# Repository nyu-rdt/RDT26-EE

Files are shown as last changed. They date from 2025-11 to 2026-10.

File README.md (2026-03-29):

# RDT26-EE
NYU Robotic Design Team Electrical Engineering subsystem repo

For help with C/C++ or using git and github, refer to training presentations in the NYU RDT 2025 - 2026 / Electrical Engineering / EE Trainings google drive

## CI Status



- `platformio-main.yml` compiles `platformio_projects/RDT_2025_26_TEENSY4_1`
- `platformio-i2c-parent.yml` compiles `general_testing/ALL_i2c_can/i2c_parent_CAN`

Both workflows run on push/pull request when those folders change, and can also be run manually from the Actions tab.

## where is the robot code?

Embedded code for robot control is / will be in [/platformio_projects](./platformio_projects). code from last years robot is in [/platformio_archive](./platformio_archive) (useful to review!) check readmes to identify the right project to use.

Review docs in [/docs](./docs) for coding style, testing, and contributing guidelines.

## where are the PCBs?

all PCBs, schematics etc. are in the Google Drive or in [/HARDWARE](./HARDWARE) folder

## new files
pls try and keep new files organized in the right folders - e.g. tests in /tests, docs in /docs, hardware files in /HARDWARE etc.

when testing things try and use the platformio test framework instead of making throwaway files.

If you do need to make such files (really want to use arduino IDE or something) please place them in [/general_testing](./general_testing) so they don't clutter the main repo.

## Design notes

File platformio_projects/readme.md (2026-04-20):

# project usage:

flags in config are mostly for testing. could move thos to test folder somehow probably. change their boolean values to enable/disable features like ramping and command timeout.

### if youre only testing:
0. connect through usb to the i2c **parent**, power child on by connecting the 3S battery
1. ensure i2c wiring is correct (sda to sda, scl to scl, gnd to gnd)
2. if code is already uploaded to both mcus just open serial monitor with `pio device monitor`
3. if you need to upload code, use the commands below. you can open two serial monitors at once to see both sides of the i2c communication and join them in vscode to see them together, or do it one at a time (in that case upload the main code first)

#### to upload main code:

```bash
pio run -t upload -d platformio_projects/RDT_2025_26_TEENSY4_1
```
or
```bash
pio run -t upload -d platformio_projects/RDT_2025_26_TEENSY4_1 --upload-port COM3
```
(upload port is optional if you just have one mcu plugged in)

#### upload test file:

```bash
pio run -t upload -d platformio_projects/i2c_parent --upload-port COM4
```
(replace COM3/4 with your actual ports - you can see which ones are connected in port menu under you terminal in vscode)

sometimes this will act up, then disconnect the other usb from your laptop while uploading, then reconnect after upload is done and it should work fine.

## corresponding test file:

testing project for parent side i2c is [/platformio_projects/i2c_parent](./../platformio_projects/i2c_parent) - lets you send loco commands via serial (WASD in serial monitor)

## opening serial monitor(s):
```bash
pio device monitor -p COM3
```
and in another terminal:
```bash
pio device monitor -p COM4
```

you can join two terminals to see both sides at once by selecting two with ctrl and rightclicking then selecting "join terminals"

in parent terminal, control direction with WASD, speed with E and Q, and stop with X or space.

## xbox controller bridge (alternative to WASD):

instead of using the serial monitor, you can plug an xbox controller into your laptop and use `platformio_projects/controller_bridge/controller_serial.py` to send commands directly.

requires:
```
pip install pygame pyserial
```

usage:
```bash
python platformio_projects/controller_bridge/controller_serial.py COM4
```
(replace COM4 with the i2c_parent Teensy's port)

| control | action |
|---|---|
| left stick | drive forward / backward |
| right stick X | turn left / right |
| A / B / Y | excavation positions |
| LB / RB / Menu | belt outward / inward / stop |
| D-pad ←/→ | bin open / close |
| D-pad ↓/↑ | vibrate on / off |
| either trigger | E-STOP |
| View button | request sensor data (printed in terminal) |

if buttons feel wrong, run with `--debug` to identify your controller's axis/button indices:
```bash
python platformio_projects/controller_bridge/controller_serial.py --debug
```

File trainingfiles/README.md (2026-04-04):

# FreeRTOS Training Projects — Teensy 4.1

Three standalone PlatformIO projects in increasing complexity. Work through them in order.

| Project | Concepts |
|---|---|
| `01_blink_rtos` | Tasks, `vTaskDelay`, `vTaskStartScheduler`, concurrency basics |
| `02_queue_mutex` | Queues, mutexes, producer/consumer pattern |
| `03_rover_i2c_can` | ISR-safe I2C→queue pipeline, task notifications, CAN bus |

---

## Setup from scratch

### 1. Create the project (PlatformIO UI)

New Project → Board: **Teensy 4.1** → Framework: **Arduino**

You get:
```
my_project/
├── include/
├── lib/
├── src/
│   └── main.cpp
└── platformio.ini
```

### 2. Edit `platformio.ini`

FreeRTOS is **not** bundled with the Teensy framework — you must declare it. Use the GitHub URL; the registry entry is unreliable.

```ini
[env:teensy41]
platform = teensy
board = teensy41
framework = arduino
monitor_speed = 115200

lib_deps =
    https://github.com/tsandmann/freertos-teensy.git
```

Add other `lib_deps` only for libraries not already bundled with Teensy. You do **not** need to add FlexCAN_T4, Wire, Servo, SPI — those ship with the Teensy framework package and are always available.

### 3. FreeRTOSConfig.h — do you need to copy it?

**No.** The library ships its own `FreeRTOSConfig.h` in its `src/` directory and `FreeRTOS.h` finds it there automatically. You do not need to copy anything for a basic build.

**Only customize it if you need to change settings.** Because `FreeRTOS.h` and `FreeRTOSConfig.h` live in the same directory inside the library, GCC always finds the library's copy first — placing one in `src/`, `include/`, or the project root does **not** override it by itself (tested).

**To override from the project root**, use the `-include` build flag in `platformio.ini`:

```ini
build_flags =
    -include "${PROJECT_DIR}/FreeRTOSConfig.h"
```

This force-injects your file before anything else, setting the `FREERTOS_CONFIG_H` include guard so the library's copy is skipped. Two caveats:
- Your config must start from the **library's** `FreeRTOSConfig.h` as a base — the port has many required settings that a generic template won't have
- If your config uses `configGENERATE_RUN_TIME_STATS == 1`, add `#include <stdint.h>` before the `uint64_t` declaration (it's injected before system headers are available)
- After changing the config, run `pio run -t clean` first — stale cached objects will cause linker errors

### 4. Customizing FreeRTOSConfig.h (optional)

You don't need to touch most of it. The fields that matter:

```c
configTICK_RATE_HZ       1000       // 1ms tick — standard, leave it
configMAX_PRIORITIES     10         // priority levels 0–9; reduce if you don't need many
configMINIMAL_STACK_SIZE 128        // words (not bytes) for the idle task stack
configUSE_MUTEXES        1          // required by port's C++ threading layer
configUSE_TASK_NOTIFICATIONS 1      // set 1 if you use xTaskNotify
configTOTAL_HEAP_SIZE    0          // 0 = use system malloc (Teensy port default)
```

Everything else either has a safe default or gets stripped by the linker if unused.

Two things already set correctly in the template:
- `configCPU_CLOCK_HZ = F_CPU` — uses the Arduino macro, matches your actual Teensy clock speed automatically
- `configSYSTICK_CLOCK_HZ = 100000UL` — Teensy-specific SysTick setting, don't change it

### 5. Write main.cpp

Include order matters for Teensy + FreeRTOS:

```cpp
#include <Arduino.h>      // always first
#include "FreeRTOS.h"
#include "task.h"
// other RTOS headers (queue.h, semphr.h, ...)
// then your own headers
```

Structure:

```cpp
void MyTask(void *pvParams) {
    for (;;) {
        // task body
        vTaskDelay(pdMS_TO_TICKS(100));
    }
}

void setup() {
    // init hardware here, before the scheduler starts
    xTaskCreate(MyTask, "MyTask", 512, NULL, 1, NULL);
    vTaskStartScheduler(); // never returns
}

void loop() {} // leave empty — the RTOS replaces loop()
```

### 6. Build

`pio run` — first build after adding lib_deps downloads the library (~30s). Subsequent builds are fast.

---

## What needs lib_deps vs what doesn't

| Library | Needs lib_deps? | Notes |
|---|---|---|
| `FlexCAN_T4` | No | Bundled with Teensy framework |
| `Wire`, `SPI`, `Servo` | No | Bundled |
| `freertos-teensy` | **Yes** | Use GitHub URL |
| `HX711` (bogde) | Yes | |
| `Encoder` (paulstoffregen) | Yes | |

---

## Key RTOS concepts by project

### 01 — Tasks and scheduling

`xTaskCreate(fn, name, stackWords, param, priority, handle)` registers a function as a task. Once `vTaskStartScheduler()` is called, the scheduler runs the highest-priority ready task. `loop()` is never called again.

`vTaskDelay(pdMS_TO_TICKS(N))` suspends the calling task for N milliseconds and lets other tasks run. Unlike Arduino `delay()`, other tasks keep executing while this one sleeps.

### 02 — Queues and mutexes

`xQueueCreate(depth, itemSize)` allocates a queue. `xQueueSend` copies data in; `xQueueReceive` blocks until data arrives. The queue owns the data — no shared pointers, no races.

A mutex (`xSemaphoreCreateMutex`) protects a shared resource. Pattern: `xSemaphoreTake → use resource → xSemaphoreGive`. Always release it, even on error paths. Never hold a mutex across a `vTaskDelay`.

**Interactive experiments** — all knobs are in `02_queue_mutex/include/config.h`. Change one value, flash, and watch Serial.

| Experiment | What to change | What to observe |
|---|---|---|
| A — fill the queue | `CONSUMER_SLOW_MS` → `2000` | `queue waiting` climbs to `QUEUE_DEPTH`, then "[Producer] WARNING: queue full" appears |
| B — drain it back | Restore `CONSUMER_SLOW_MS` → `0` | `queue waiting` drops to 0 within a few seconds |
| C — shrink the buffer | `QUEUE_DEPTH` → `1`, `PRODUCER_PERIOD_MS` → `100` | Drops appear almost every cycle |
| D — watch heap drop | `TASK_STACK_WORDS` → `4096` | `free heap` in status block drops by ~43 KB (3 tasks × 3584 extra words × 4 bytes) |
| E — stack overflow | `TASK_STACK_WORDS` → `96` | Overflow hook fires immediately; device halts — reset to recover |

The status block prints every `PRINTER_PERIOD_MS` ms. Reduce it to `500` if you want faster feedback during experiments.

### 03 — ISR safety and task notifications

Wire callbacks run at interrupt level. Two rules:
1. Never call blocking RTOS functions from an ISR
2. Use `*FromISR` variants only: `xQueueSendFromISR`, `xSemaphoreGiveFromISR`, etc.
3. Always call `portYIELD_FROM_ISR(woken)` at the end of the ISR

Task notifications are lighter than queues for single-flag signals. `xTaskNotify(handle, value, eSetValueWithOverwrite)` sends directly to a task handle. The receiving task calls `xTaskNotifyWait`. Used in project 03 to bypass the command queue for E-stop — guarantees the stop takes effect at the top of the next motor cycle regardless of what's queued.

`vTaskDelayUntil(&lastWake, period)` is the correct way to write a fixed-period task. `vTaskDelay(20)` drifts by execution time each cycle; `vTaskDelayUntil` wakes at absolute tick intervals.

**Interactive experiments** — all knobs are in `03_rover_i2c_can/include/config.h`. Requires a second Teensy sending I2C commands (or use `general_testing/ALL_i2c_can/i2c_parent_CAN`).

| Experiment | What to change | What to observe |
|---|---|---|
| A — CAN without hardware | `SIMULATE_CAN` → `0` (no motors connected) | System freezes; E-stop does nothing — CAN bus-off error-interrupt storm starves all tasks |
| B — I2C queue overflow | `I2C_QUEUE_DEPTH` → `2`, send a burst of commands | ISR drops bytes; commands arrive garbled or not at all |
| C — motor queue overflow | `MOTOR_QUEUE_DEPTH` → `1`, send commands faster than 20ms | "[I2CDecode] WARNING: motor queue full" appears |
| D — instant speed | `MAX_SPEED_DELTA_PER_TICK` → `0.5` | `[CAN SIM]` speed jumps to target in one tick instead of ramping |
| E — slow ramp | `MAX_SPEED_DELTA_PER_TICK` → `0.002` | Speed takes ~10s to reach full; useful for seeing the slew effect |
| F — command timeout | `COMMAND_TIMEOUT_MS` → `100`, stop sending I2C | `[CAN SIM]` speeds ramp to 0 within 100ms of the last command |
| G — E-stop debounce | `ESTOP_DEBOUNCE_MS` → `1` | Brief noise on pin 3 triggers false E-stops |
| H — stack vs heap | `MOTOR_TASK_STACK` → `4096` | Free heap drops by ~14 KB; visible if you add a `Serial.printf` in the motor loop |

> **Note on experiment A:** the freeze happens because the CAN controller has no termination resistor and no ACK from any node. It accumulates TX errors, enters bus-off, and the error-recovery interrupt fires thousands of times per second — faster than FreeRTOS can schedule tasks. `SIMULATE_CAN 1` skips the real write and prints `[CAN SIM]` lines instead.

---

## Reference

- FreeRTOS docs: https://www.freertos.org/Documentation/00-Overview
- tsandmann port: https://github.com/tsandmann/freertos-teensy

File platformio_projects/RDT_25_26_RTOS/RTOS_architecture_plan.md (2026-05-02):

# RTOS Detailed Architecture Plan

## 1) Purpose

This document turns the exploration notes into a concrete implementation plan for the RTOS migration.

Primary goals:
- Use hardware timing for stepper pulse generation
- Use normalized command/state plumbing for deterministic behavior
- Keep safety decisions centralized and enforceable
- Preserve software telemetry and software e-stop command handling during hardware kill-switch e-stop

## 2) Architecture Decisions Locked In

1. Stepper pulse timing is moved to hardware timer ISR (not loop cadence).
2. I2C receive ISR stays minimal and only pushes bytes to queue.
3. Commands are decoded into normalized desired-state data (not direct module calls in ISR path).
4. Safety owns timeout detection and publishes safety bits globally.
5. Actuator tasks enforce safety bits every cycle.
6. While hardware kill-switch is active:
   - Allow `GRP_CONTROL` and `GRP_DATA`
   - Reject motion/mechanism command groups

## 3) High-Level Topology

```mermaid
flowchart LR
    J[Jetson / I2C Master] --> RXISR[I2C RX ISR]
    RXISR --> QRX[(qI2cRxBytes)]
    QRX --> CMD[CmdDecodeTask]
    CMD --> DS[(DesiredState)]

    SAF[SafetyTask] --> EGS[(EventGroup: SafetyBits)]
    SAF -->|notify hard-stop| MOT[MotorControlTask]
    SAF -->|notify hard-stop| MEC[MechanismTask]

    DS --> MOT
    DS --> MEC
    EGS --> MOT
    EGS --> MEC

    MOT --> MCAN{{mCanTx}}
    MEC --> MCAN
    MCAN --> CAN[CAN Driver]

    MEC --> STEPPLAN[(StepperPulsePlan)]
    STEPISR[Stepper Timer ISR] --> STEPDRV[STEP pin pulses]
    STEPPLAN --> STEPISR

    SNS[SensorTask] --> SNAP[(SensorSnapshot)]
    EGS --> TEL[TelemetryTask]
    SNAP --> TEL
    TEL --> TBUF[(Telemetry Buffer A/B)]
    REQISR[I2C Request ISR] --> TBUF
    TBUF --> J
```

## 4) Task Set and Scheduling

Assumption: `configMAX_PRIORITIES = 10` (0 is idle).

| Task | Priority | Trigger | Period/Block | Initial Stack (words) | Responsibility |
|---|---:|---|---|---:|---|
| `SafetyTask` | 7 | periodic | 5 ms | 512 | Relay status, timeout detection, safety bit updates, hard-stop notifications |
| `DebugTask` | 1 | periodic | 50-100 ms | 640 | Serial/Teleplot output only |

Interrupt handlers:
- I2C RX ISR: queue push only (`xQueueSendFromISR`)
- I2C Request ISR: send latest ready telemetry buffer only
- Stepper Timer ISR: pin toggling only, no RTOS API calls

## 5) RTOS Primitives

### Queues

| Name | Type | Depth | Producer | Consumer | Notes |
|---|---|---:|---|---|---|
| `qI2cRxBytes` | `uint8_t` | 32 | I2C RX ISR | `CmdDecodeTask` | Byte ingress decoupling; overflow counter for diagnostics |

### Event Group

`egSafetyBits` (written by `SafetyTask`, read by control tasks):
- `SAFETY_HW_ESTOP`
- `SAFETY_SW_ESTOP`
- `SAFETY_COMMS_TIMEOUT`
- `SAFETY_OVERCURRENT`
- `SAFETY_LATCHED_STOP` (optional if we want explicit reset semantics)

### Mutexes

| Name | Protects | Users |
|---|---|---|
| `mCanTx` | CAN peripheral transaction sequence | `MotorControlTask`, `MechanismTask` |
| `mDesiredState` | `DesiredState` struct | `CmdDecodeTask` writer, actuator task readers |

### Task Notifications

- `SafetyTask` -> `MotorControlTask`: hard-stop notification bit
- `SafetyTask` -> `MechanismTask`: hard-stop notification bit

Use notifications for low-latency stop signaling; use event bits for persistent safety state.

## 6) Shared Data Contracts

### `DesiredState`

Single source of operator intent, updated only by `CmdDecodeTask`.

```c
typedef struct {
    float loco_left_target;      // normalized -1..1 after duty scaling
    float loco_right_target;     // normalized -1..1 after duty scaling
    float excav_belt_target;     // normalized -1..1 after duty scaling
    int8_t excav_vert_dir;       // -1,0,+1
    int8_t depo_door_cmd;        // -1 close, 0 hold, +1 open
    int8_t depo_vib_cmd;         // -1,0,+1
    uint32_t last_cmd_ms;        // for timeout logic
} DesiredState;
```

### `SensorSnapshot`

Prepared by `SensorTask`, read by `TelemetryTask` and optional debug.

### `StepperPulsePlan`

Shared with timer ISR.

```c
    volatile uint8_t enabled;        // 0/1
    volatile uint8_t dir;            // 0=down, 1=up
```

## 7) Hardware-Timed Stepper Plan

Implementation strategy:
1. Configure `IntervalTimer` at boot with an ISR callback.
2. ISR toggles STEP pin each invocation if `enabled==1`.
3. `MechanismTask` updates `StepperPulsePlan` (dir/enabled/period) from desired state and limits.
4. ISR reads plan and runs without dynamic allocation, queues, or prints.

Benefits:
- Pulse quality independent of RTOS task jitter
- Cleaner mechanism task code (task makes decisions, ISR makes pulses)
- Easier to prove maximum missed-step risk

Constraints:
- Use `digitalWriteFast` or direct GPIO for ISR speed
- Keep ISR constant-time and branch-light
- Guard shared plan updates with critical section or atomic write strategy

## 8) Command Policy and Gating

Command validation is centralized in `CmdDecodeTask`. The kill-switch gating policy has been validated against the prototype and is kept as-is:

```text
if HW kill-switch estop active:
  allow groups: CONTROL, DATA
  reject groups: locomotion, excavation, deposition
else:
  allow all valid groups
```

SW can still send software e-stop/reset semantics. Actuator-changing commands are blocked while hardware e-stop is active.

For any multi-byte command extension, axis/register mapping must be defined explicitly in named constants before field deployment. Parser tests covering both axis variants are required before any multi-byte extension ships. This was a source of ambiguity in the prototype and is a hard guardrail going forward.

## 9) Control Flow Sequences

```mermaid
sequenceDiagram
    participant Master as I2C Master
    participant DS as DesiredState

    CMD->>DS: write normalized targets (mutex)
```

```mermaid
sequenceDiagram
    participant SAF as SafetyTask

    SAF->>SAF: read relay + now-last_cmd_ms
    SAF-->>MEC: notify hard-stop if asserted
    MOT->>MOT: force outputs zero if any safety-stop bit
```

```mermaid
sequenceDiagram
    participant BUF as Double Buffer
    participant REQ as I2C Request ISR

    SNS->>TEL: latest sensor snapshot
    REQ->>BUF: read active packet pointer
    REQ->>Master: Wire2.write(packet, DATA_PACKET_SIZE)
```

## 10) Safety State Ownership

Single-writer policy:
- `SafetyTask` is the only writer of `egSafetyBits`.

Consumers:
- `CmdDecodeTask` reads for command gating.
- `MotorControlTask` and `MechanismTask` read for enforcement.
- `TelemetryTask` reads for packet flags.

This avoids conflicting stop logic spread across multiple modules.

The low-latency task notification path from `SafetyTask` to actuator tasks is kept in addition to the persistent event bits — the notification handles the immediate hard-stop response, the bits handle steady-state enforcement. Both are required.

## 11) File/Module Layout (Planned)

```text
RDT_25_26_RTOS/
  include/
    rtos_types.h
    rtos_config.h
    safety_bits.h
  src/
    main.cpp
    rtos/
      app_init.cpp
      isr_i2c.cpp
      isr_stepper_timer.cpp
      task_safety.cpp
      task_cmd_decode.cpp
      task_motor_control.cpp
      task_mechanism.cpp
      task_sensor.cpp
      task_telemetry.cpp
      task_debug.cpp
      shared_state.cpp
```

## 12) Step-by-Step Implementation Plan

### Phase A: Kernel scaffold
- Add FreeRTOS lib dependency
- Create task skeletons and all RTOS primitives
- Keep outputs disabled by default

### Phase B: Safety backbone
- Implement `SafetyTask` + safety event bits
- Add hard-stop notification path to control tasks
- Add counters for transitions and timeout events

### Phase C: Command plumbing
- Add RX ISR queue and `CmdDecodeTask`
- Implement normalized `DesiredState`
- Implement command gating rules for kill-switch mode
- Define all multi-byte command axis/register mappings as named constants at this phase; do not defer

### Phase D: Actuator control tasks
- Move locomotion/excav belt CAN logic into `MotorControlTask` (20 ms)
- Move deposition + stepper control decisions into `MechanismTask` (5 ms)
- Introduce hardware timer ISR for stepper pulse generation

### Phase E: Sensors and telemetry
- Add `SensorTask` snapshot generation
- Add `TelemetryTask` packet build + double buffer
- Keep I2C request ISR minimal and deterministic
- Keep legacy telemetry packet compatibility for parent bring-up tools
- Add explicit byte-count assertions for every serialized `GRP_DATA` register; these must be verified against the active superloop serializer, not assumed

### Phase F: Debug and tuning
- Add debug task
- Enable stack high-water mark and heap monitoring behind a debug flag during migration; remove or gate behind flag before competition build
- Tune queue depths, task stacks, and periods using measured runtime

## 13) Acceptance Criteria

1. With kill-switch e-stop active:
   - Data request responses continue at expected packet length
   - `GRP_CONTROL` accepted
   - Motion/mechanism command groups rejected

2. Timeout behavior:
   - No command for `COMMAND_TIMEOUT_MS` sets timeout safety bit
   - Actuator outputs are forced to safe state within one control period

3. Stepper timing:
   - Pulse jitter stays bounded by timer ISR, independent of command burst load

4. Stability:
   - No queue overflows in normal command rate
   - If overflow occurs, system remains safe and counters expose fault

5. Parent compatibility:
   - `i2c_parent` command keys (`WASD`, excavation, deposition, stop, estop) operate the RTOS child without protocol remapping
   - Legacy data request path returns expected packet length for current bench scripts; this must be verified with an explicit test that sends a `GRP_DATA` request and checks the response byte count

6. Pin parity:
   - Child pin assignments for relay, current mux, encoders, stepper, deposition door, and vib motor match the active superloop `pins.h` unless explicitly documented as variant-only
   - Migration acceptance includes a cross-check against the active superloop pin map; undocumented divergences are a blocking failure

7. Protocol robustness:
   - Multi-byte command extensions include explicit axis/register mapping constants
   - Serializer outputs are verified against expected byte lengths per register; encode/decode round-trip checks are required for all bit-packed telemetry fields

## 14) Instrumentation to Add Early

- `i2c_rx_overflow_count`
- `cmd_rejected_killswitch_count`
- `cmd_decode_invalid_count`
- `timeout_event_count`
- `safety_transition_count`
- `max_task_exec_us` per critical task
- `telemetry_serialize_error_count`
- `i2c_response_short_packet_count`

These make bring-up and competition debugging much faster.

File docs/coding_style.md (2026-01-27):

# Coding Style Guide

Guidelines for keeping the codebase readable. Not strict rules - use your judgment.

This doc is also useful context for AI assistants (Copilot, Claude, etc.) when working on the codebase.

---

## Naming

| Thing | Style | Example |
|---|---|---|
| Files | `snake_case` | `can_driver.cpp` |
| Functions | Module prefix + descriptive | `CAN_SendSpeed()`, `Sensors_Init()` |
| Variables | `camelCase` | `motorSpeed`, `encoderCount` |
| Constants | `ALL_CAPS` | `CAN_BAUD_RATE`, `PIN_MOTOR_PWM` |

The module prefix (like `CAN_`, `Sensors_`) helps identify where functions come from since C++ doesn't have namespaces in the Arduino world.

---

## File Structure

**Header files (.h):**
```cpp
#ifndef MODULE_NAME_H
#define MODULE_NAME_H

#include <Arduino.h>

void Module_Init(void);
void Module_DoThing(int param);

#endif
```

**Source files (.cpp):**
```cpp
#include "module_name.h"
#include "config.h"

static int s_internalVariable = 0;  // static = file-private

void Module_Init(void) {
    // setup code
    Serial.println("Module ready");
}

void Module_DoThing(int param) {
    // implementation
}
```

---

## Comments

```cpp
// Use comments to explain WHY, not WHAT
// Bad: increment counter
// Good: increment to track missed CAN messages for timeout detection

// Mark things that need attention
// TODO: add timeout handling
// FIXME: this breaks if speed > 1.0
// VERIFIED: tested on hardware 2026-01-26

// For functions that others will call, brief description is helpful
/**
 * Send speed command to motor over CAN
 * @param canId Motor's CAN address
 * @param speed -1.0 to 1.0
 */
void CAN_SendSpeed(uint32_t canId, float speed);
```

---

## Hardware-Specific Stuff

**Put all pins in config.h:**
```cpp
// config.h
#define PIN_MOTOR_PWM       11
#define PIN_ESTOP_RELAY     2
#define PIN_STRING_POT      A3
```

**Volatile for interrupt variables:**
```cpp
volatile long encoderCount = 0;  // modified in ISR

void encoderISR(void) {
    encoderCount++;
}
```

**Protect shared data:**
```cpp
long getEncoderCount(void) {
    noInterrupts();
    long count = encoderCount;
    interrupts();
    return count;
}
```

---

## Avoid Magic Numbers

```cpp
// Bad
if (reading > 512) { ... }

// Good
#define SENSOR_THRESHOLD 512
if (reading > SENSOR_THRESHOLD) { ... }
```

---

## Error Handling

Check if things worked, especially hardware:
```cpp
if (!CAN_Init()) {
    Serial.println("ERROR: CAN failed to init");
    // handle it somehow
}
```

---

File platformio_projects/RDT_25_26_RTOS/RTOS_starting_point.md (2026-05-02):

# RTOS Starting Point

Reference projects:
- `trainingfiles/01_blink_rtos`
- `trainingfiles/02_queue_mutex`
- `trainingfiles/03_rover_i2c_can`

Common setup pattern:
- `platformio.ini` adds `https://github.com/tsandmann/freertos-teensy.git`
- `setup()` creates tasks and calls `vTaskStartScheduler()`
- `loop()` is intentionally empty
- `Arduino.h` is included before FreeRTOS headers
- ISR paths use `*FromISR` APIs and `portYIELD_FROM_ISR(...)`

Architecture pattern used in `03_rover_i2c_can`:
- ISR only captures bytes quickly and pushes to a queue
- Decode/command logic runs in a task
- Motor control runs in a fixed-period task (`vTaskDelayUntil`)
- E-stop runs in a high-priority task and notifies motor task directly

This pattern is a strong match for our current rover firmware constraints.

## Current superloop snapshot (RDT_2025_26_TEENSY4_1)

`ROVER_update()` currently does:
1. `EE_BOX_Update()`
2. E-stop relay check and possible `ESTOP_Trigger()`
3. Command handling (`newCommand` + `processCommand`)
4. Timeout check (`COMMAND_TIMEOUT_MS`)
5. Periodic subsystem updates:
   - `LOCO_Update()`
   - `EXCAV_Update()`
   - `CURRENT_SENSORS_Update()` (optional)
   - `LOAD_CELL_Update()` (optional)
   - `DEPO_Update()`
   - `COMMS_UpdateFlags()`
   - `DEBUG_Update()` (optional)

## Candidate task split

### Task A: E-stop / safety monitor (highest)
- Responsibility:
  - Read relay state (`EE_BOX_Update` + `EE_BOX_IsRelayEngaged`)
  - Trigger emergency stop immediately on unsafe state
  - Notify motor/control task of hard-stop state
- Why high priority:
  - Safety path; must preempt normal control work
- Target period:
  - 5-10 ms

### Task B: I2C RX + command decode
- Responsibility:
  - ISR captures incoming I2C bytes to queue
  - Task decodes command byte into actions/targets
  - Writes command target state (or pushes decoded command struct)
- Why:
  - Keeps ISR minimal and deterministic
  - Prevents command parsing from blocking time-critical loops
- Trigger model:
  - Event-driven via queue receive (block until data)

### Task C: Motor/control loop (locomotion + excavation command application)
- Responsibility:
  - Apply latest target commands
  - Handle ramp logic at fixed rate (`TX_PERIOD_MS = 20`)
  - Send CAN commands
  - Enforce comms timeout fail-safe
- Why:
  - This is the rover control heartbeat
  - Fixed periodic timing is important for predictable motion
- Target period:
  - 20 ms (`50 Hz`)

### Task D: Mechanism maintenance loop
- Responsibility:
  - `EXCAV_Update()` (stepper + limit logic + optional pot checks)
  - `DEPO_Update()` (door state machine)
- Why:
  - Mechanism internals are periodic but less safety-critical than Task A/C
- Target period:
  - 5-10 ms for stepper smoothness (or split stepper to use a hardware timer interrupt if jitter is an issue)

### Task E: Sensor + flags loop
- Responsibility:
  - `CURRENT_SENSORS_Update()`
  - `LOAD_CELL_Update()`
  - `COMMS_UpdateFlags()`
- Why:
  - These feed telemetry and health flags; useful but not motor-heartbeat critical
- Target period:
  - 10 ms for current mux stepping
  - 50-100 ms acceptable for aggregate flags publishing

### Task F: Debug/telemetry print loop (lowest)
- Responsibility:
  - `DEBUG_Update()` serial plot output
- Why low priority:
  - Human-facing output should never starve safety/control
- Target period:
  - Existing `PLOT_PERIOD_MS` (50 ms) or slower if serial load is high

## Proposed priority order (initial)

1. Task A `EStopSafety` (highest)
2. Task C `MotorControl`
3. Task B `I2CDecode`
4. Task D `MechanismUpdate`
5. Task E `SensorsAndFlags`
6. Task F `DebugTelemetry` (lowest)

Notes:
- If command latency becomes visible, raise Task B above Task C and let Task C consume latest decoded state each cycle.

## Init placement strategy

Use a two-level init pattern:

1. `setup()` does board/global bring-up before scheduler:
- Serial (optional)
- Pin mode defaults for safety outputs
- CAN peripheral init
- I2C bus init and callback registration
- Queue/mutex/task-notification primitive creation
- Task creation and scheduler start

2. Each task does module-local one-time init before its loop:
- Example: initialize task-local timestamps/state variables
- Then enter `for (;;)` loop with `vTaskDelay`/`vTaskDelayUntil`

This mirrors the training projects and keeps task ownership clear.

## Suggested migration phases

1. RTOS scaffold only:
- Add FreeRTOS dependency and empty task skeletons
- Keep behavior equivalent to current firmware

2. Move safety + command pipeline:
- Add ISR queue + decode task
- Add E-stop safety task + notification path

3. Move control heartbeat:
- Create 20 ms motor control task using `vTaskDelayUntil`
- Remove superloop control timing logic

4. Move slower periodic work:
- Sensors, flags, debug prints

5. Tune priorities and stack sizes with runtime measurements.

## Open questions before implementation

- Should stepper pulse timing stay in a shared mechanism task, or become a dedicated high-rate task or hardware timer interrupt from day one?
- Do we want timeout handling only in MotorControl (single owner), or mirrored in Safety task too?
- Should command decoding directly call handlers, or write a normalized command struct consumed by MotorControl/Mechanism tasks?

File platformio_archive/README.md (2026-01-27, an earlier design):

# PlatformIO Archive (Legacy Code)

> ⚠️ **LEGACY CODE** - This folder contains archived firmware from the 2024-2025 competition season. It is kept for reference but is no longer actively developed.

This folder contains PlatformIO-based firmware projects for the RDT26-EE excavation rover.

---

## 🎯 Project Reference

| Project | Status | Use Case |
|---|---|---|
| **[RDT_2024_PF](./RDT_2024_PF/)** | 📦 Archived | Modular architecture for Teensy 4.1 - most complete legacy code |
| [2024_teensy_original](./2024_teensy_original/) | 📦 Archived | Single-file version for Teensy 4.1 |
| [2024_STM32_migr](./2024_STM32_migr/) | ⚠️ Outdated | STM32 port - incomplete, missing features |
| [stm32_rtos_2024](./stm32_rtos_2024/) | ⚠️ Outdated | STM32 + FreeRTOS - incomplete, missing features |

**This is archived code.** For the current robot codebase, check the main repository or ask the team lead.

---

## Project Descriptions

### RDT_2024_PF (Most Complete)
**Platform:** Teensy 4.1 | **Framework:** Arduino | **Status:** 📦 Archived

The most complete archived codebase for the excavation rover. Features a clean modular architecture:
- Separate modules for locomotion, excavation, sensors, CAN, I2C, and system control
- Full support for rotary encoders, HX711 load cells, E-stop relay
- CAN bus motor control at 500kbps
- I2C slave interface for Raspberry Pi communication

```
RDT_2024_PF/
├── include/          # Header files for each module
├── src/              # Implementation files
├── lib/HX711/        # Load cell library
└── platformio.ini    # Build configuration
```

**Build:** `cd RDT_2024_PF && pio run`

See [RDT_2024_PF/README.md](./RDT_2024_PF/README.md) for detailed system documentation.

---

### 2024_teensy_original
**Platform:** Teensy 4.1 | **Framework:** Arduino

The original single-file implementation (~1000 lines in `main.cpp`). This is the reference implementation that `RDT_2024_PF` was modularized from. Contains all features but is harder to navigate and maintain.

Use this if you need to:
- Compare behavior with the modular version
- Understand the original implementation intent
- Debug issues by testing against a known-working version

**Build:** `cd 2024_teensy_original && pio run`

---

### 2024_STM32_migr
**Platform:** STM32F446RE | **Framework:** STM32Cube HAL

⚠️ **Not currently in use** - This was a port to STM32, but it's based on an older version of the code that's missing:
- Rotary encoder support
- E-stop relay handling
- CAN-based belt motor control
- Updated pin mappings

If we decide to migrate to STM32 in the future, this project will need to be updated to match `RDT_2024_PF`.

---

### stm32_rtos_2024
**Platform:** STM32F446RE | **Framework:** STM32Cube HAL + FreeRTOS

⚠️ **Not currently in use** - Same as `2024_STM32_migr` but with FreeRTOS for real-time task scheduling. Also based on outdated code.

Contains a custom FreeRTOS configuration but would need significant updates before use.

---

## Getting Started

### Prerequisites
1. Install [PlatformIO](https://platformio.org/install) (VS Code extension recommended)
2. Install Teensy platform: `pio pkg install -g -p teensy`

### Building
```bash
# Navigate to desired project
cd RDT_2024_PF

# Build
pio run

# Build and upload to connected Teensy
pio run -t upload

# Monitor serial output
pio device monitor -b 115200
```

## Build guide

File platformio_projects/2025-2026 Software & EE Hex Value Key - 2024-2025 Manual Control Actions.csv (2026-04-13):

Category | Subcategory | 1st Nibble |  | 2nd Nibble |  | Final Hex | Description
 |  | Command | Hex | Value | Hex
 |  | Emergency Stop | 0 |  | 1 | 0 1 | Still deciding whether we want commands to be remembered during a stop
Locomotion |  | Locomotion Stop | 1 | Locomotion Stop | 0 | 1 0 | Stops moving forward/ backward and turning
 |  | Forward | 2 | 25% | 0 | 2 0 | Move forward at VALUE% of max speed
 |  |  | 2 | 50% | 1 | 2 1
 |  |  | 2 | 75% | 2 | 2 2
 |  |  | 2 | 100% | 3 | 2 3
 |  | Backward | 3 | 25% | 0 | 3 0 | Move backward at VALUE% of max speed
 |  |  | 3 | 50% | 1 | 3 1
 |  |  | 3 | 75% | 2 | 3 2
 |  |  | 3 | 100% | 3 | 3 3
 |  | Left | 4 | 25% | 0 | 4 0 | Move left at VALUE% of max speed (forward in right wheels backward in left wheels)
 |  |  | 4 | 50% | 1 | 4 1
 |  |  | 4 | 75% | 2 | 4 2
 |  |  | 4 | 100% | 3 | 4 3
 |  | Right | 5 | 25% | 0 | 5 0 | Move right at VALUE% of max speed (forward in left wheels backward in right wheels)
 |  |  | 5 | 50% | 1 | 5 1
 |  |  | 5 | 75% | 2 | 5 2
 |  |  | 5 | 100% | 3 | 5 3
Excavation |  | Exacavation Conveyor Actions | 6 | Stop Excavation Conveyor | 0 | 6 0 | Store the current position of the excavation conveyor as "locomotion position"
 |  |  | 6 | Locomotion Position | 1 | 6 1 | Move the excavation conveyor to its locomotion position
 |  |  | 6 | Excavation Position | 2 | 6 2 | Move the excavation conveyor to its excavation position
 |  |  | 6 | Belt Stop | 3 | 6 3 | Stop the belt movement
 |  |  | 6 | Belt Outward | 4 | 6 4 | Move the belt in reverse
 |  |  | 6 | Belt Inward | 5 | 6 5 | Digging and collecting the material
Construction |  | Depo Bin | 7 | Open Door | 0 | 7 0 | Open depo bin door
 |  |  | 7 | Close Door | 1 | 7 1 | Close depo bin door
 |  |  | 7 | Turn on Vibration Motor | 2 | 7 2 | Turn on vibration motor to remove regolith from bin
 |  |  | 7 | Turn off Vibration Motor | 3 | 7 3 | Turn off vibration motor
Other |  | Request Data | 8 | Request data | 0 | 8 0 | sensor flags, byte data by this doc
 |  | Switch to Autonomous Control | 8 | Switch to Autonomous Control | 1 | 8 1 | Sends signal to "switch to autonomous control" and to start interpreting actions acording to the autonomous control scheme (see other sheet). Stops all motion (wheels, pivot and belt) before switching.

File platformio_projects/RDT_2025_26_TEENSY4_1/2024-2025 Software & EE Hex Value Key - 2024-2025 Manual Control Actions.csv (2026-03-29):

Category | Subcategory | 1st Nibble |  | 2nd Nibble |  | Final Hex | Description
 |  | Command | Hex | Value | Hex
 |  | Emergency Stop | 0 |  | 1 | 0 1 | Still deciding whether we want commands to be remembered during a stop
Locomotion |  | Locomotion Stop | 1 | Locomotion Stop | 0 | 1 0 | Stops moving forward/ backward and turning
 |  | Forward | 2 | 25% | 0 | 2 0 | Move forward at VALUE% of max speed
 |  |  | 2 | 50% | 1 | 2 1
 |  |  | 2 | 75% | 2 | 2 2
 |  |  | 2 | 100% | 3 | 2 3
 |  | Backward | 3 | 25% | 0 | 3 0 | Move backward at VALUE% of max speed
 |  |  | 3 | 50% | 1 | 3 1
 |  |  | 3 | 75% | 2 | 3 2
 |  |  | 3 | 100% | 3 | 3 3
 |  | Left | 4 | 25% | 0 | 4 0 | Move left at VALUE% of max speed (forward in right wheels backward in left wheels)
 |  |  | 4 | 50% | 1 | 4 1
 |  |  | 4 | 75% | 2 | 4 2
 |  |  | 4 | 100% | 3 | 4 3
 |  | Right | 5 | 25% | 0 | 5 0 | Move right at VALUE% of max speed (forward in left wheels backward in right wheels)
 |  |  | 5 | 50% | 1 | 5 1
 |  |  | 5 | 75% | 2 | 5 2
 |  |  | 5 | 100% | 3 | 5 3
Excavation/Construction |  | Exacavation Conveyor Actions | 6 | Zero Excavation Conveyor | 0 | 6 0 | Store the current position of the excavation conveyor as "locomotion position" STOP MOVEMENT OF ACME SCREW
 |  |  | 6 | Locomotion Position | 1 | 6 1 | Move the excavation conveyor to its locomotion position
 |  |  | 6 | Excavation Position | 2 | 6 2 | Move the excavation conveyor to its excavation position
 |  |  | 6 | Belt Stop | 3 | 6 3 | Stop the belt movement
 |  |  | 6 | Belt Outward | 4 | 6 4 | Move the belt in reverse
 |  |  | 6 | Belt Inward | 5 | 6 5 | Digging and collecting the material
 |  | Deposition Conveyor Actions | 7 | Rotate Collection | 0 | 7 0 | Rotating the belt to collect from the shovel into the construction bin
 |  |  | 7 | Rotate Dumping | 1 | 7 1 | Rotating the belt to move the dirt from construction
 |  |  | 7 | Stop rotating | 2 | 7 2 | Stop the belt
Other |  | Request Data | 8 | Request data | 0 | 8 0 | Weight collected, position (locomotion, excavation, deposition), distance travelled.
 |  | Switch to Autonomous Control | 8 | Switch to Autonomous Control | 1 | 8 1 | Sends signal to "switch to autonomous control" and to start interpreting actions acording to the autonomous control scheme (see other sheet). Stops all motion (wheels, pivot and belt) before switching.
 |  | 1. depo now has a door controler by a linear actuator |  | open door
 |  |  |  | close door
 |  |  |  | ???
 |  | 2. depo now has a vibration motor controlled through PWM |  | turn on
 |  |  |  | turn off
 |  |  |  | ? do we want intensity variation?

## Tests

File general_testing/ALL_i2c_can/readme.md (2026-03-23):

# all the platformio projects in this folder are for testing the i2c and can bus communication between the teensy and another teensy (to be replaced by jetson send same command strucutre)

## Currently used:

The most complete child project (that is/will be integrated into full system) is [/i2c_can_child_tony](./i2c_can_child_tony)

The project used to test it is [/i2c_parent_CAN](./i2c_parent_CAN) but obviosuly that should be handled by the software team and their python-based code on the jetson

These only have the implementation for locomotion control but they form a foundation for the rest of the system and have stubs for excav and depo. the actual project is in [/platformio_projects\RDT_2025_26_TEENSY4_1](../../platformio_projects/RDT_2025_26_TEENSY4_1)

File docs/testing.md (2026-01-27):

# Testing with PlatformIO

This guide explains how to write and run tests for the rover firmware.

---

## What Are PlatformIO Tests?

Tests let you upload **alternative code** to the Teensy to verify that specific parts of the system work correctly. Instead of running the full rover firmware, you run focused test code that exercises one subsystem at a time.

This is useful for:
- Verifying hardware works before full integration
- Debugging issues in isolation
- Testing new components as they're assembled

---

## How Testing Works

### Normal Build (`pio run`)
Compiles and uploads the main firmware from `src/main.cpp`.

### Test Build (`pio test`)
Compiles and uploads code from the `test/` folder instead. Your test file provides its own `setup()` and `loop()` functions.

The main `src/main.cpp` is **not included** during test builds—your test takes its place.

---

## Running Tests

### Run a Specific Test
```bash
pio test -f test_blink
```
This compiles and uploads just the `test_blink` test.

### Run All Tests
```bash
pio test
```
Runs each test in the `test/` folder sequentially.

### View Serial Output
Open the Serial Monitor to see test output:
```bash
pio device monitor
```

---

## Test Folder Structure

Each test lives in its own subfolder under `test/`:

```
test/
├── test_blink/
│   └── test_blink.cpp
├── test_can/
│   └── test_can.cpp
├── test_motor/
│   └── test_motor.cpp
└── test_sensors/
    └── test_sensors.cpp
```

The folder name determines the test name used with `pio test -f`.

---

## Writing a Basic Test

A test file is a complete Arduino program with `setup()` and `loop()`:

```cpp
// test/test_blink/test_blink.cpp

#include <Arduino.h>

void setup() {
    Serial.begin(115200);
    pinMode(LED_BUILTIN, OUTPUT);
    Serial.println("=== Blink Test ===");
}

void loop() {
    digitalWrite(LED_BUILTIN, HIGH);
    Serial.println("LED ON");
    delay(500);
    
    digitalWrite(LED_BUILTIN, LOW);
    Serial.println("LED OFF");
    delay(500);
}
```

Run with:
```bash
pio test -f test_blink
```

---

## Testing a Subsystem

You can import modules from `src/` and `include/` to test them:

```cpp
// test/test_can/test_can.cpp

#include <Arduino.h>
#include "can_driver.h"

void setup() {
    Serial.begin(115200);
    delay(2000);  // Wait for Serial Monitor to connect
    
    Serial.println("=== CAN Driver Test ===");
    
    // Test initialization
    if (CAN_Init()) {
        Serial.println("CAN init: PASS");
    } else {
        Serial.println("CAN init: FAIL");
        return;
    }
    
    // Test sending a message
    Serial.println("Sending test message to motor 0x78...");
    CAN_SendMotorSpeed(0x78, 0.0);
    Serial.println("Message sent - verify motor controller received it");
}

void loop() {
    // Test complete - nothing to do
}
```

---

## Interactive Testing

For hardware testing, it's often useful to control the test from the Serial Monitor:

```cpp
// test/test_motor_interactive/test_motor_interactive.cpp

#include <Arduino.h>
#include "locomotion.h"
#include "can_driver.h"

void setup() {
    Serial.begin(115200);
    delay(2000);
    
    CAN_Init();
    
    Serial.println("=== Motor Interactive Test ===");
    Serial.println("Commands:");
    Serial.println("  f = Forward");
    Serial.println("  b = Backward");
    Serial.println("  s = Stop");
}

void loop() {
    if (Serial.available()) {
        char cmd = Serial.read();
        
        switch (cmd) {
            case 'f':
                Serial.println("Moving forward...");
                Locomotion_Forward(0.25);
                break;
            case 'b':
                Serial.println("Moving backward...");
                Locomotion_Backward(0.25);
                break;
            case 's':
                Serial.println("Stopping...");
                Locomotion_Stop();
                break;
        }
    }
}
```

Open the Serial Monitor (`pio device monitor`) and type commands to control the robot.

---

## Testing Hardware Before Integration

When bringing up new hardware, write a minimal test that exercises just that component:

```cpp
// test/test_single_motor/test_single_motor.cpp
// Test one motor before wiring all four

#include <Arduino.h>
#include <FlexCAN_T4.h>

FlexCAN_T4<CAN1, RX_SIZE_256, TX_SIZE_16> can1;

#define MOTOR_CAN_ID  0x78  // Change to the motor you're testing

void setup() {
    Serial.begin(115200);
    delay(2000);
    
    can1.begin();
    can1.setBaudRate(500000);
    
    Serial.println("=== Single Motor Test ===");
    Serial.print("Testing motor ID: 0x");
    Serial.println(MOTOR_CAN_ID, HEX);
}

void loop() {
    // Send speed command
    CAN_message_t msg;
    msg.flags.extended = 1;
    msg.id = MOTOR_CAN_ID;
    msg.len = 4;
    
    int32_t speed = 25000;  // 25% speed (0.25 * 100000)
    msg.buf[0] = (speed >> 24) & 0xFF;
    msg.buf[1] = (speed >> 16) & 0xFF;
    msg.buf[2] = (speed >> 8) & 0xFF;
    msg.buf[3] = speed & 0xFF;
    
    can1.write(msg);
    Serial.println("Sent speed command");
    
    delay(100);
}
```

---

## Using the Unity Test Framework

For automated pass/fail testing, PlatformIO includes the Unity framework:

```cpp
// test/test_example/test_example.cpp

#include <Arduino.h>
#include <unity.h>
#include "can_driver.h"

void test_can_initialization(void) {
    bool result = CAN_Init();
    TEST_ASSERT_TRUE(result);
}

void test_speed_calculation(void) {
    // Test that speed conversion works correctly
    int expected = 25000;
    int actual = (int)(0.25 * 100000);
    TEST_ASSERT_EQUAL(expected, actual);
}

void setup() {
    delay(2000);
    
    UNITY_BEGIN();
    
    RUN_TEST(test_can_initialization);
    RUN_TEST(test_speed_calculation);
    
    UNITY_END();
}

void loop() {
    // Tests run in setup(), nothing needed here
}
```

Output:
```
test/test_example.cpp:7:test_can_initialization    [PASSED]
test/test_example.cpp:12:test_speed_calculation    [PASSED]
-----------------------
2 Tests 0 Failures 0 Ignored
```

### Common Unity Assertions

| Assertion | Purpose |
|---|---|
| `TEST_ASSERT_TRUE(condition)` | Verify condition is true |
| `TEST_ASSERT_FALSE(condition)` | Verify condition is false |
| `TEST_ASSERT_EQUAL(expected, actual)` | Verify integers are equal |
| `TEST_ASSERT_EQUAL_FLOAT(exp, act, delta)` | Verify floats are close |
| `TEST_ASSERT_NULL(pointer)` | Verify pointer is null |
| `TEST_ASSERT_NOT_NULL(pointer)` | Verify pointer is not null |

---

## Important Notes

### Restore Main Firmware After Testing
After running tests, the Teensy contains test code, not the main firmware. Upload the real firmware:
```bash
pio run -t upload
```

### Test One Thing at a Time
Tests are most useful when they focus on a single subsystem. If a test fails, you know exactly where the problem is.

### Keep Tests in Version Control
Test files serve as documentation for how to use each subsystem. They help new team members understand the hardware.

### Safety
When testing motors:
- Always have E-Stop accessible
- Have another person present for first-time motor tests
- Start with low speeds (25%)

---

## Quick Reference

| Command | Description |
|---|---|
| `pio test` | Run all tests |
| `pio test -f test_name` | Run specific test |
| `pio device monitor` | Open Serial Monitor |
| `pio run -t upload` | Upload main firmware |

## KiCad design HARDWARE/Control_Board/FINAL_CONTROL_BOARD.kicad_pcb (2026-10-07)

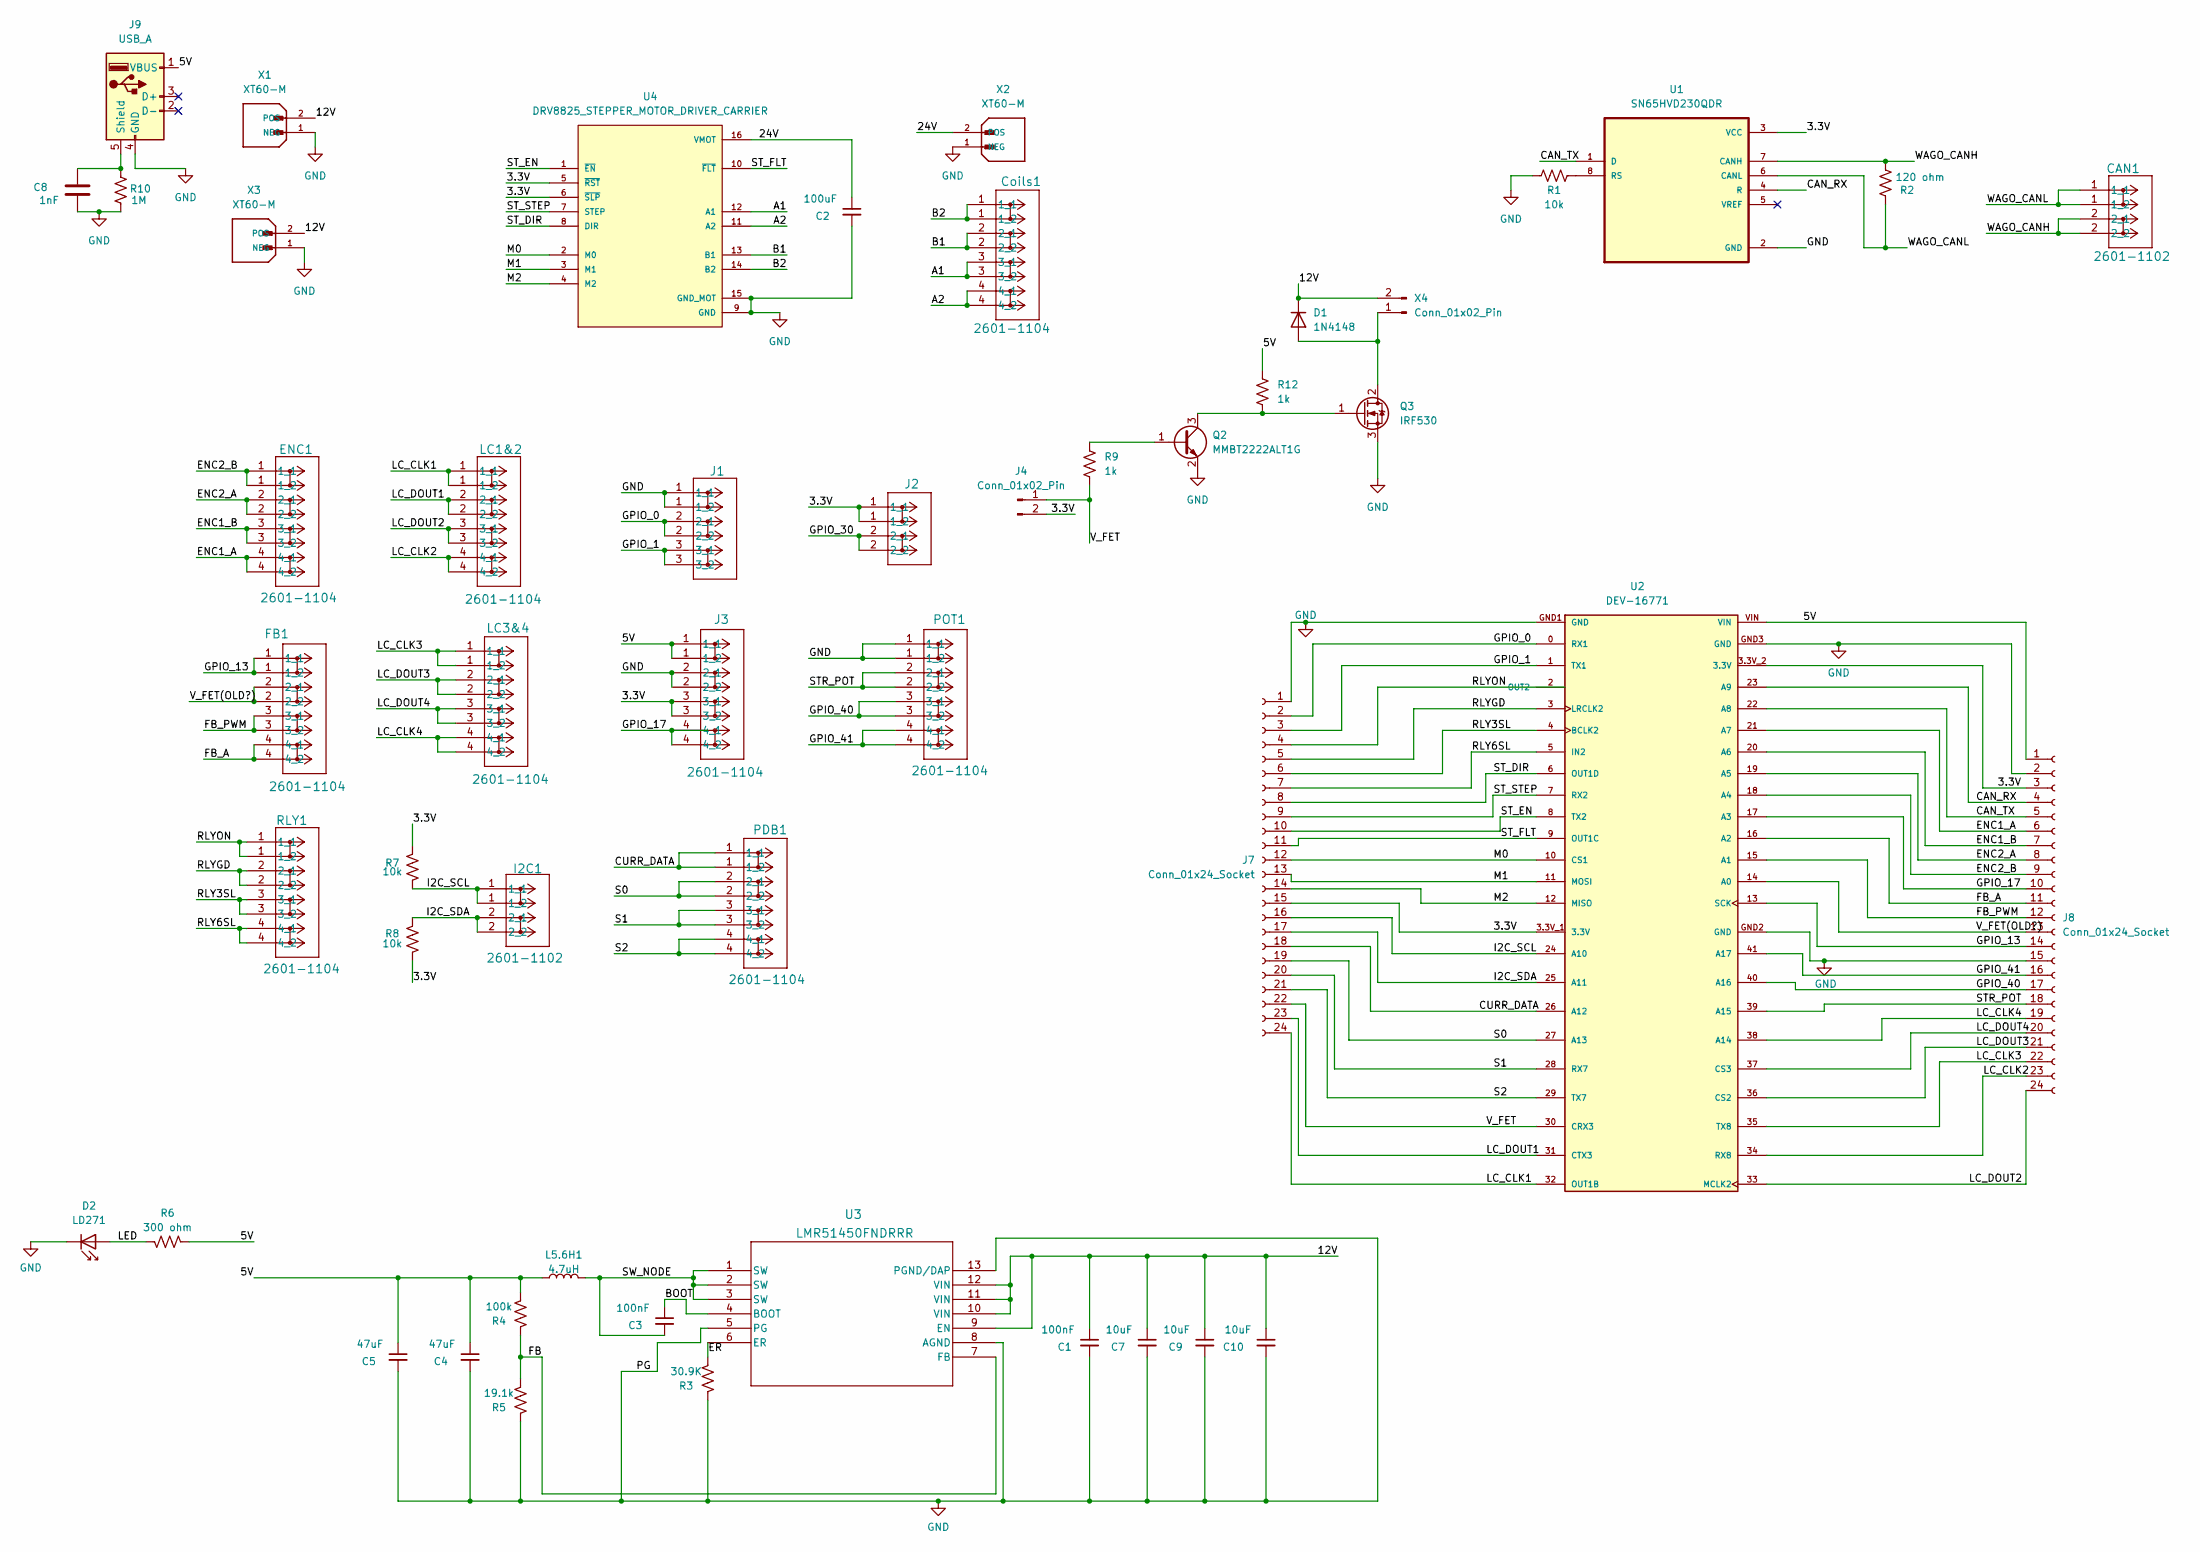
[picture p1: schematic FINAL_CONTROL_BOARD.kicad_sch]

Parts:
C1, C3: 100nF; C_0402_1005Metric_Pad0.74x0.62mm_HandSolder
C2: 100uF; C_Radial_D6.3mm_H5.0mm_P2.50mm
C4, C5: 47uF; C_1210_3225Metric_Pad1.33x2.70mm_HandSolder
C7, C9, C10: 10uF; C_0805_2012Metric_Pad1.18x1.45mm_HandSolder
C8: 1nF; C_0805_2012Metric_Pad1.18x1.45mm_HandSolder
CAN1: 2601-1102; CONN2_2601-1102_WAG
Coils1: 2601-1104; CONN4_2601-1104_WAG
D1: 1N4148; D_DO-35_SOD27_P7.62mm_Horizontal
D2: LD271; LED_D5.0mm
ENC1: 2601-1104; CONN4_2601-1104_WAG
FB1: 2601-1104; CONN4_2601-1104_WAG
I2C1: 2601-1102; CONN2_2601-1102_WAG
J1: 2604-1103; CONN3_2601-1103_WAG
J2: 236-402/334-604; CONN2_2601-1102_WAG
J3: 2601-1104; CONN4_2601-1104_WAG
J4: Conn_01x02_Pin; PinHeader_1x02_P2.54mm_Vertical
J7, J8: Conn_01x24_Socket; PinHeader_1x24_P2.54mm_Vertical
J9: USB_A; USB_A_TE_292303-4
L5.6H1: 4.7uH; L_Coilcraft_XAL6060-XXX
LC1&2, LC3&4: 2601-1104; CONN4_2601-1104_WAG
PDB1: 2601-1104; CONN4_2601-1104_WAG
POT1: 2601-1104; CONN4_2601-1104_WAG
Q2: MMBT2222ALT1G; SOT-23
Q3: IRF530; TO-220-3_Vertical
R1, R7, R8: 10k; R_0805_2012Metric
R2: 120 ohm; R_0805_2012Metric
R3: 30.9K; R_0805_2012Metric
R4: 100k; R_0805_2012Metric
R5: 19.1k; R_0805_2012Metric
R6: 300 ohm; R_0805_2012Metric
R9, R12: 1k; R_0805_2012Metric
R10: 1M; R_0805_2012Metric_Pad1.20x1.40mm_HandSolder
RLY1: 2601-1104; CONN4_2601-1104_WAG
U1: SN65HVD230QDR; SOIC127P599X175-8N
U2: DEV-16771; teensy4.1
U3: LMR51450FNDRRR; WSON_SDRRR_TEX
U4: DRV8825_STEPPER_MOTOR_DRIVER_CARRIER; IC_DRV8825_STEPPER_MOTOR_DRIVER_CARRIER
X1, X2, X3: XT60-M; AMASS_XT60-M; PARTREV V1.2
X4: Conn_01x02_Pin; AMASS_XT60-M

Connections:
/3.3V: J2.1 (1_1), J3.3 (3_1), J4.2, J7.15, J8.3, R7.2, R8.2, U1.3 (VCC), U2.3.3V_1 (3.3V), U2.3.3V_2 (3.3V), U4.5 (~RST), U4.6 (~SLP)
/5V: C4.1, C5.1, J3.1 (1_1), J8.1, J9.1 (VBUS), L5.6H1.2, R4.2, R6.2, R12.1, U2.VIN
/12V: C1.1, C7.1, C9.1, C10.1, D1.1 (K), U3.9 (EN), U3.10 (VIN), U3.11 (VIN), U3.12 (VIN), X1.2 (POS), X3.2 (POS), X4.2
/24V: C2.1, U4.16 (VMOT), X2.2 (POS)
/A1: Coils1.3 (3_1), U4.12 (A1)
/A2: Coils1.4 (4_1), U4.11 (A2)
/B1: Coils1.2 (2_1), U4.13 (B1)
/B2: Coils1.1 (1_1), U4.14 (B2)
/BOOT: C3.1, U3.4 (BOOT)
/CAN_RX: J8.4, U1.4 (R), U2.23 (A9)
/CAN_TX: J8.5, U1.1 (D), U2.22 (A8)
/CURR_DATA: J7.18, PDB1.1 (1_1), U2.26 (A12)
/ENC1_A: ENC1.4 (4_1), J8.6, U2.21 (A7)
/ENC1_B: ENC1.3 (3_1), J8.7, U2.20 (A6)
/ENC2_A: ENC1.2 (2_1), J8.8, U2.19 (A5)
/ENC2_B: ENC1.1 (1_1), J8.9, U2.18 (A4)
/ER: R3.2, U3.6 (ER)
/FB: R4.1, R5.2, U3.7 (FB)
/FB_A: FB1.4 (4_1), J8.11, U2.16 (A2)
/FB_PWM: FB1.3 (3_1), J8.12, U2.15 (A1)
/GPIO_0: J1.2 (2_1), J7.2, U2.0 (RX1)
/GPIO_1: J1.3 (3_1), J7.3, U2.1 (TX1)
/GPIO_13: FB1.1 (1_1), J8.14, U2.13 (SCK)
/GPIO_17: J3.4 (4_1), J8.10, U2.17 (A3)
/GPIO_30: J2.2 (2_1)
/GPIO_40: J8.17, POT1.3 (3_1), U2.40 (A16)
/GPIO_41: J8.16, POT1.4 (4_1), U2.41 (A17)
/I2C_SCL: I2C1.1 (1_1), J7.16, R7.1, U2.24 (A10)
/I2C_SDA: I2C1.2 (2_1), J7.17, R8.1, U2.25 (A11)
/LC_CLK1: J7.24, LC1&2.1 (1_1), U2.32 (OUT1B)
/LC_CLK2: J8.23, LC1&2.4 (4_1), U2.34 (RX8)
/LC_CLK3: J8.22, LC3&4.1 (1_1), U2.35 (TX8)
/LC_CLK4: J8.19, LC3&4.4 (4_1), U2.38 (A14)
/LC_DOUT1: J7.23, LC1&2.2 (2_1), U2.31 (CTX3)
/LC_DOUT2: J8.24, LC1&2.3 (3_1), U2.33 (MCLK2)
/LC_DOUT3: J8.21, LC3&4.2 (2_1), U2.36 (CS2)
/LC_DOUT4: J8.20, LC3&4.3 (3_1), U2.37 (CS3)
/LED: D2.2 (A), R6.1
/M0: J7.12, U2.10 (CS1), U4.2 (M0)
/M1: J7.13, U2.11 (MOSI), U4.3 (M1)
/M2: J7.14, U2.12 (MISO), U4.4 (M2)
/RLY3SL: J7.6, RLY1.3 (3_1), U2.4 (BCLK2)
/RLY6SL: J7.7, RLY1.4 (4_1), U2.5 (IN2)
/RLYGD: J7.5, RLY1.2 (2_1), U2.3 (LRCLK2)
/RLYON: J7.4, RLY1.1 (1_1), U2.2 (OUT2)
/S0: J7.19, PDB1.2 (2_1), U2.27 (A13)
/S1: J7.20, PDB1.3 (3_1), U2.28 (RX7)
/S2: J7.21, PDB1.4 (4_1), U2.29 (TX7)
/STR_POT: J8.18, POT1.2 (2_1), U2.39 (A15)
/ST_DIR: J7.8, U2.6 (OUT1D), U4.8 (DIR)
/ST_EN: J7.10, U2.8 (TX2), U4.1 (~EN)
/ST_FLT: J7.11, U2.9 (OUT1C), U4.10 (~FLT)
/ST_STEP: J7.9, U2.7 (RX2), U4.7 (STEP)
/SW_NODE: C3.2, L5.6H1.1, U3.1 (SW), U3.2 (SW), U3.3 (SW)
/V_FET: J4.1, J7.22, R9.2, U2.30 (CRX3)
/V_FET(OLD?): FB1.2 (2_1), J8.13, U2.14 (A0)
/WAGO_CANH: CAN1.2 (2_1), R2.2, U1.7 (CANH)
/WAGO_CANL: CAN1.1 (1_1), R2.1, U1.6 (CANL)
GND: C1.2, C2.2, C4.2, C5.2, C7.2, C8.2, C9.2, C10.2, D2.1 (K), J1.1 (1_1), J3.2 (2_2), J7.1, J8.2, J8.15, J9.4 (GND), POT1.1 (1_1), Q2.2 (E), Q3.3 (S), R1.1, R3.1, R5.1, R10.2, U1.2 (GND), U2.GND1 (GND), U2.GND2 (GND), U2.GND3 (GND), U3.5 (PG), U3.8 (AGND), U3.13 (PGND/DAP), U4.9 (GND), U4.15 (GND_MOT), X1.1 (NEG), X2.1 (NEG), X3.1 (NEG)
unnamed: D1.2 (A), Q3.2 (D), X4.1
unnamed: C8.1, J9.5 (Shield), R10.1
unnamed: Q2.1 (B), R9.1
unnamed: Q2.3 (C), Q3.1 (G), R12.2
unnamed: R1.2, U1.8 (RS)

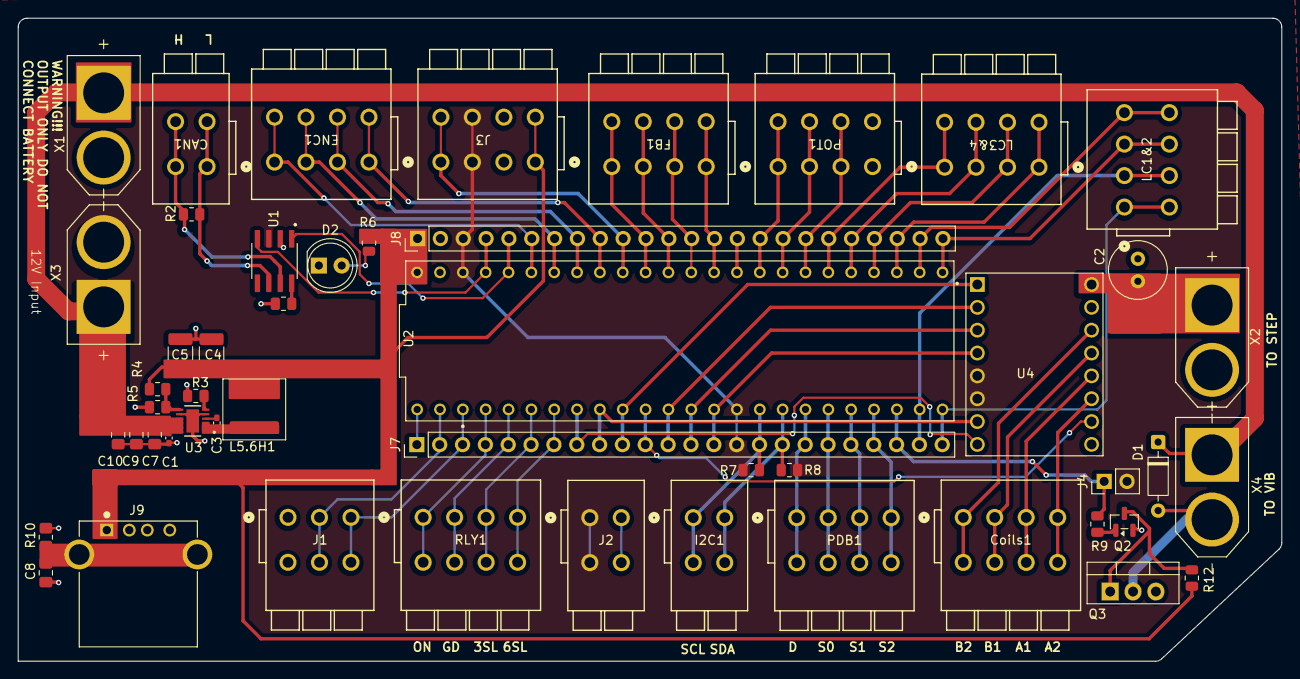
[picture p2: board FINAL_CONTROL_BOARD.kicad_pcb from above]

Board: 2 copper layers, 140.5 x 71.5 mm, 50 parts (0 on the bottom side), 63 nets.

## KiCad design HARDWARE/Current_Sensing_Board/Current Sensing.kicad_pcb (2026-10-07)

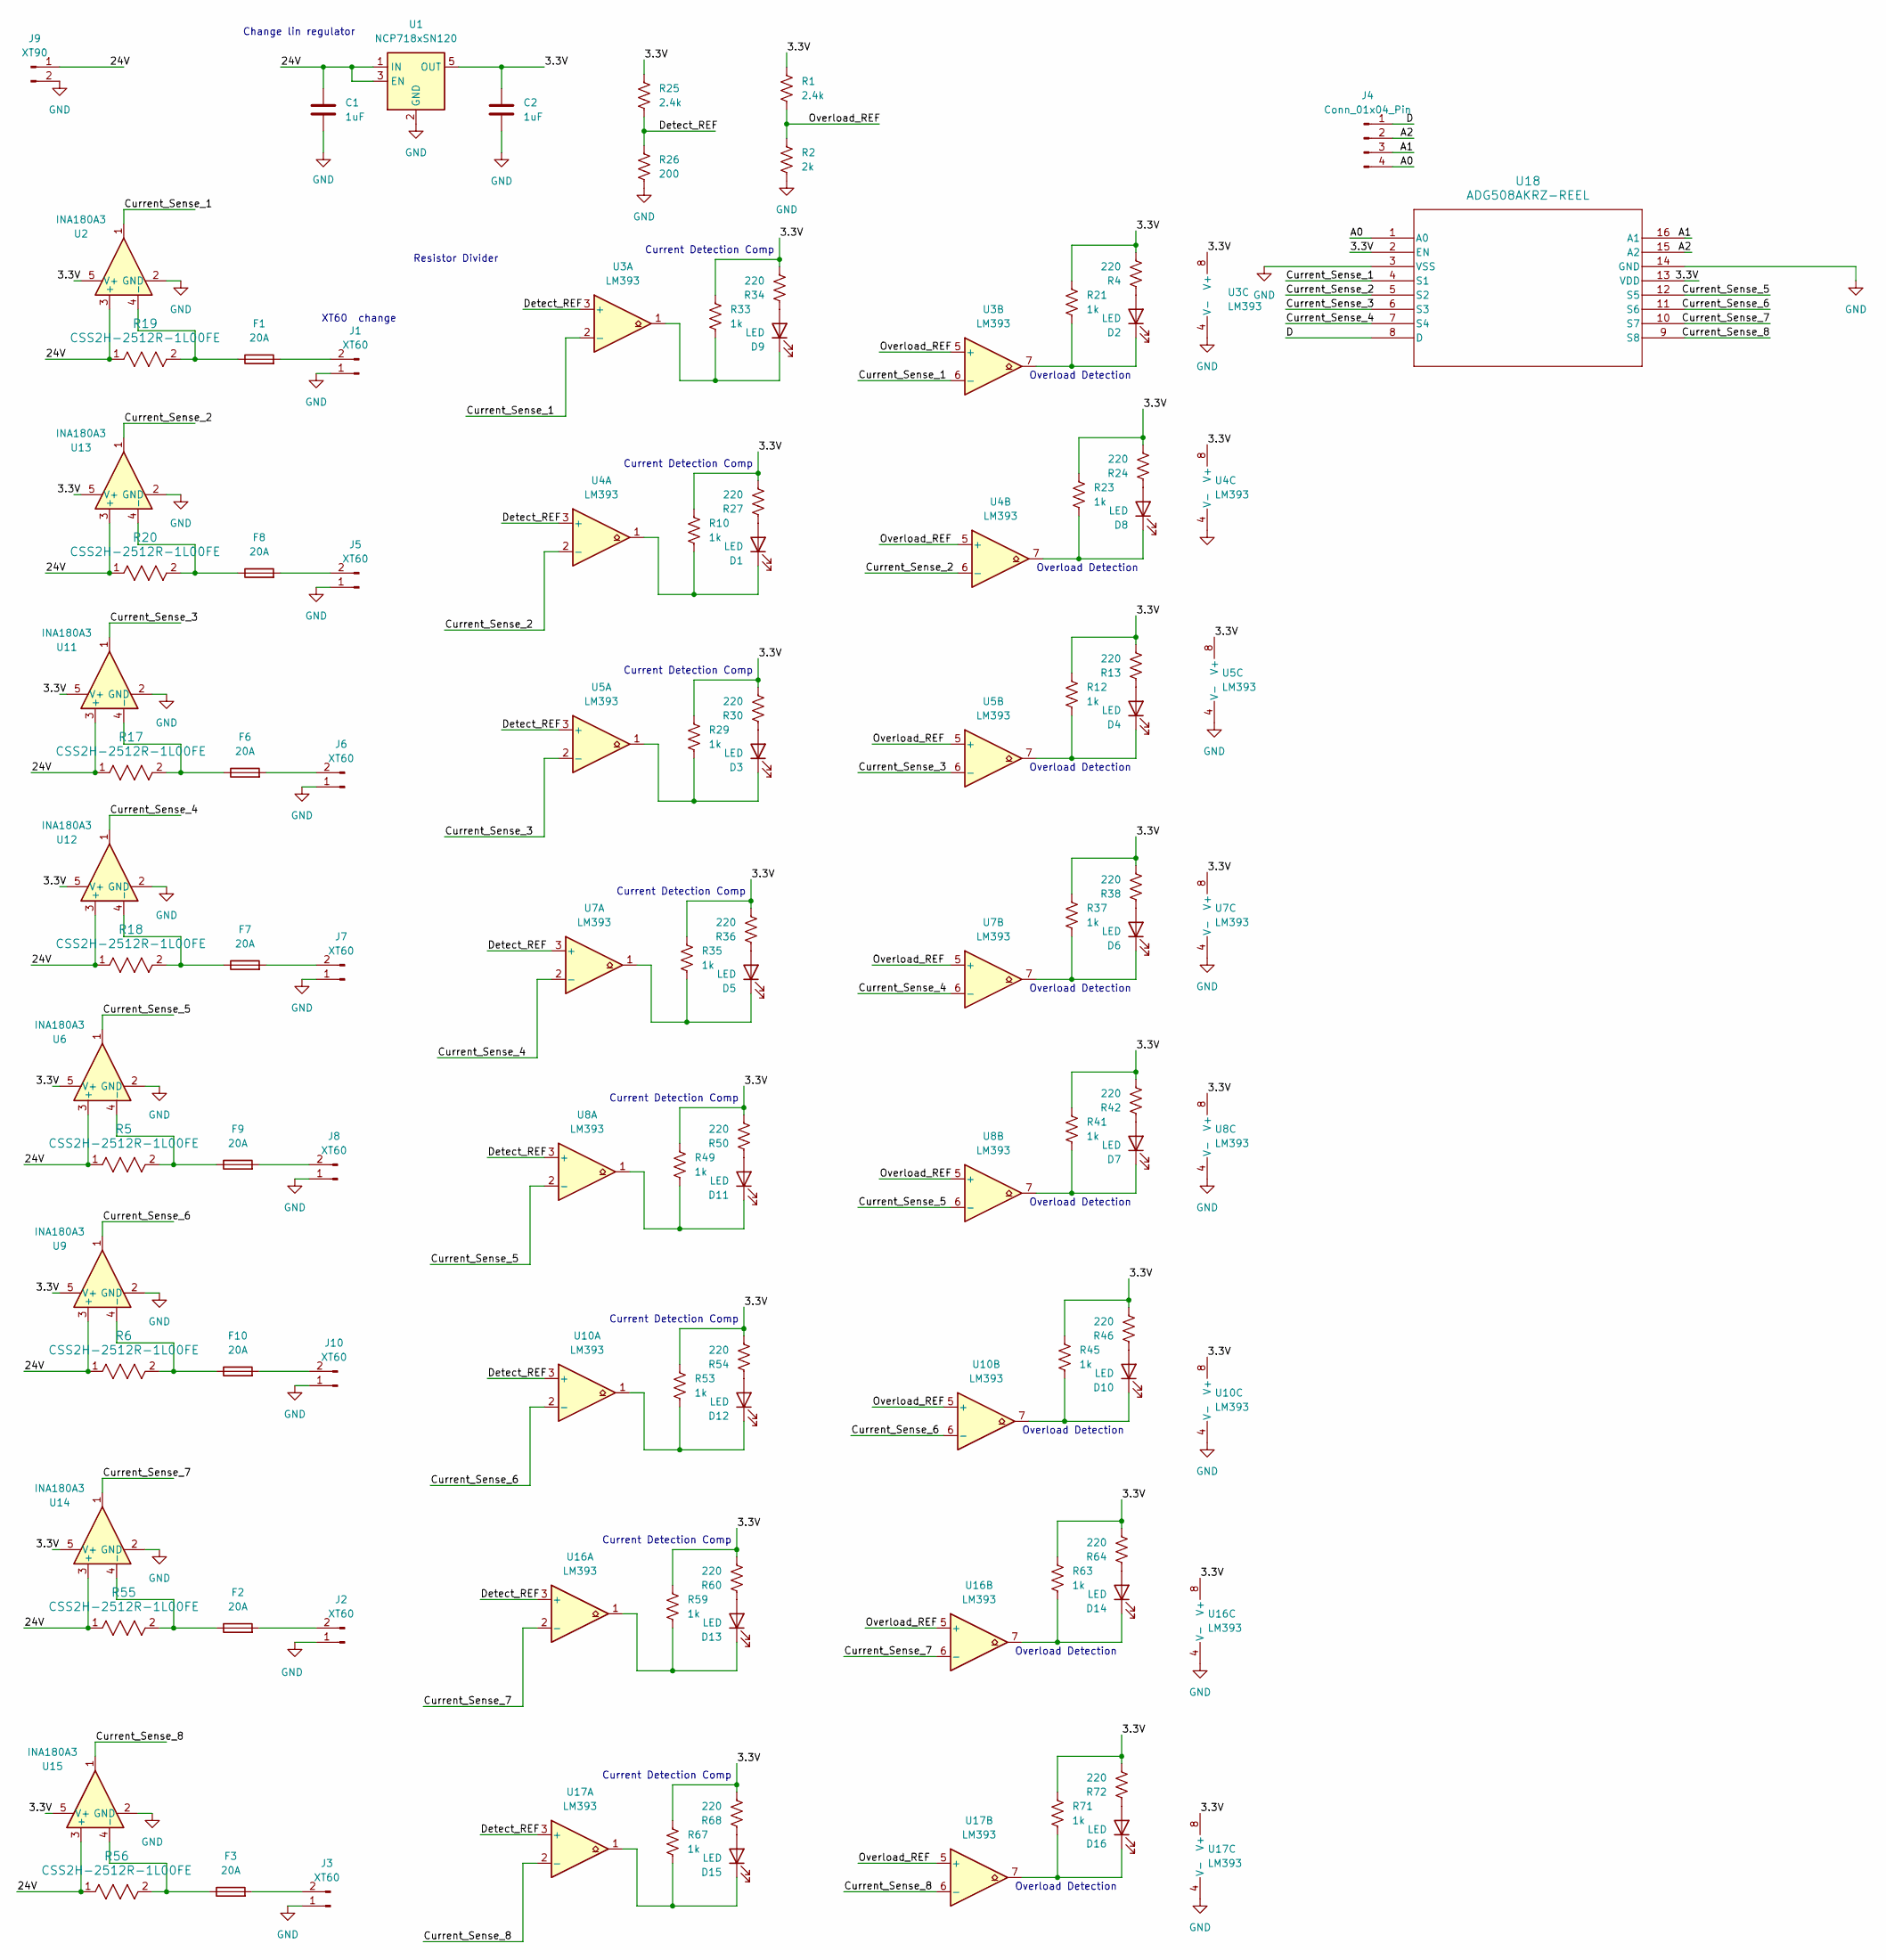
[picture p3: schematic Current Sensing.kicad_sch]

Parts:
C1, C2: 1uF; C_0603_1608Metric
D1, D2, D3, D4, D5, D6, D7, D8, D9, D10, D11, D12, D13, D14, D15, D16: LED; LED_D5.0mm
F1, F2, F3, F6, F7, F8, F9, F10: 20A; FUSE_3544-2
J1, J2, J3, J5, J6, J7, J8, J10: XT60; AMASS_XT60-F_1x02_P7.20mm_Vertical
J4: Conn_01x04_Pin; TerminalBlock_WAGO_2601-1104_1x04_P3.50mm_Horizontal
J9: XT90; XT90_vertical
R1, R25: 2.4k; R_0603_1608Metric
R2: 2k; R_0603_1608Metric
R4, R13, R24, R27, R30, R34, R36, R38, R42, R46, R50, R54, R60, R64, R68, R72: 220; R_0603_1608Metric
R5, R6, R17, R18, R19, R20, R55, R56: CSS2H-2512R-1L00FE; R_2512_6332Metric
R10, R12, R21, R23, R29, R33, R35, R37, R41, R45, R49, R53, R59, R63, R67, R71: 1k; R_0603_1608Metric
R26: 200; R_0603_1608Metric
U1: NCP718xSN120; SOT-23-5
U2, U6, U9, U11, U12, U13, U14, U15: INA180A3; SOT-23-5
U3, U4, U5, U7, U8, U10, U16, U17: LM393; SOIC-8_3.9x4.9mm_P1.27mm
U18: ADG508AKRZ-REEL; SOIC-16_3.9x9.9mm_P1.27mm

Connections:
/3.3V: C2.1, R1.1, R4.2, R10.1, R12.1, R13.2, R21.1, R23.1, R24.2, R25.1, R27.2, R29.1, R30.2, R33.1, R34.2, R35.1, R36.2, R37.1, R38.2, R41.1, R42.2, R45.1, R46.2, R49.1, R50.2, R53.1, R54.2, R59.1, R60.2, R63.1, R64.2, R67.1, R68.2, R71.1, R72.2, U1.5 (OUT), U2.5 (V+), U3.8 (V+), U4.8 (V+), U5.8 (V+), U6.5 (V+), U7.8 (V+), U8.8 (V+), U9.5 (V+), U10.8 (V+), U11.5 (V+), U12.5 (V+), U13.5 (V+), U14.5 (V+), U15.5 (V+), U16.8 (V+), U17.8 (V+), U18.2 (EN), U18.13 (VDD)
/24V: C1.1, J9.1, R5.1, R6.1, R17.1, R18.1, R19.1, R20.1, R55.1, R56.1, U1.1 (IN), U1.3 (EN), U2.3 (+), U6.3 (+), U9.3 (+), U11.3 (+), U12.3 (+), U13.3 (+), U14.3 (+), U15.3 (+)
/A0: J4.4, U18.1 (A0)
/A1: J4.3, U18.16 (A1)
/A2: J4.2, U18.15 (A2)
/Current_Sense_1: U2.1, U3.2 (-), U3.6 (-), U18.4 (S1)
/Current_Sense_2: U4.2 (-), U4.6 (-), U13.1, U18.5 (S2)
/Current_Sense_3: U5.2 (-), U5.6 (-), U11.1, U18.6 (S3)
/Current_Sense_4: U7.2 (-), U7.6 (-), U12.1, U18.7 (S4)
/Current_Sense_5: U6.1, U8.2 (-), U8.6 (-), U18.12 (S5)
/Current_Sense_6: U9.1, U10.2 (-), U10.6 (-), U18.11 (S6)
/Current_Sense_7: U14.1, U16.2 (-), U16.6 (-), U18.10 (S7)
/Current_Sense_8: U15.1, U17.2 (-), U17.6 (-), U18.9 (S8)
/D: J4.1, U18.8 (D)
/Detect_REF: R25.2, R26.1, U3.3 (+), U4.3 (+), U5.3 (+), U7.3 (+), U8.3 (+), U10.3 (+), U16.3 (+), U17.3 (+)
/Overload_REF: R1.2, R2.1, U3.5 (+), U4.5 (+), U5.5 (+), U7.5 (+), U8.5 (+), U10.5 (+), U16.5 (+), U17.5 (+)
GND: C1.2, C2.2, J1.1 (Pin_2), J2.1 (Pin_2), J3.1 (Pin_2), J5.1 (Pin_2), J6.1 (Pin_2), J7.1 (Pin_2), J8.1 (Pin_2), J9.2, J10.1 (Pin_2), R2.2, R26.2, U1.2 (GND), U2.2 (GND), U3.4 (V-), U4.4 (V-), U5.4 (V-), U6.2 (GND), U7.4 (V-), U8.4 (V-), U9.2 (GND), U10.4 (V-), U11.2 (GND), U12.2 (GND), U13.2 (GND), U14.2 (GND), U15.2 (GND), U16.4 (V-), U17.4 (V-), U18.3 (VSS), U18.14 (GND)
unnamed: D1.2 (A), R27.1
unnamed: D1.1 (K), R10.2, U4.1
unnamed: D2.2 (A), R4.1
unnamed: D2.1 (K), R21.2, U3.7
unnamed: D3.2 (A), R30.1
unnamed: D3.1 (K), R29.2, U5.1
unnamed: D4.2 (A), R13.1
unnamed: D4.1 (K), R12.2, U5.7
unnamed: D5.2 (A), R36.1
unnamed: D5.1 (K), R35.2, U7.1
unnamed: D6.2 (A), R38.1
unnamed: D6.1 (K), R37.2, U7.7
unnamed: D7.2 (A), R42.1
unnamed: D7.1 (K), R41.2, U8.7
unnamed: D8.2 (A), R24.1
unnamed: D8.1 (K), R23.2, U4.7
unnamed: D9.2 (A), R34.1
unnamed: D9.1 (K), R33.2, U3.1
unnamed: D10.2 (A), R46.1
unnamed: D10.1 (K), R45.2, U10.7
unnamed: D11.2 (A), R50.1
unnamed: D11.1 (K), R49.2, U8.1
unnamed: D12.2 (A), R54.1
unnamed: D12.1 (K), R53.2, U10.1
unnamed: D13.2 (A), R60.1
unnamed: D13.1 (K), R59.2, U16.1
unnamed: D14.2 (A), R64.1
unnamed: D14.1 (K), R63.2, U16.7
unnamed: D15.2 (A), R68.1
unnamed: D15.1 (K), R67.2, U17.1
unnamed: D16.2 (A), R72.1
unnamed: D16.1 (K), R71.2, U17.7
unnamed: F1.2, J1.2 (Pin_1)
unnamed: F2.2, J2.2 (Pin_1)
unnamed: F3.2, J3.2 (Pin_1)
unnamed: F8.2, J5.2 (Pin_1)
unnamed: F6.2, J6.2 (Pin_1)
unnamed: F7.2, J7.2 (Pin_1)
unnamed: F9.2, J8.2 (Pin_1)
unnamed: F10.2, J10.2 (Pin_1)
unnamed: F1.1, R19.2, U2.4 (-)
unnamed: F9.1, R5.2, U6.4 (-)
unnamed: F10.1, R6.2, U9.4 (-)
unnamed: F6.1, R17.2, U11.4 (-)
unnamed: F7.1, R18.2, U12.4 (-)
unnamed: F8.1, R20.2, U13.4 (-)
unnamed: F2.1, R55.2, U14.4 (-)
unnamed: F3.1, R56.2, U15.4 (-)

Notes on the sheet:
Overload Detection
Resistor Divider
Current Detection Comp
Change lin regulator
XT60 change

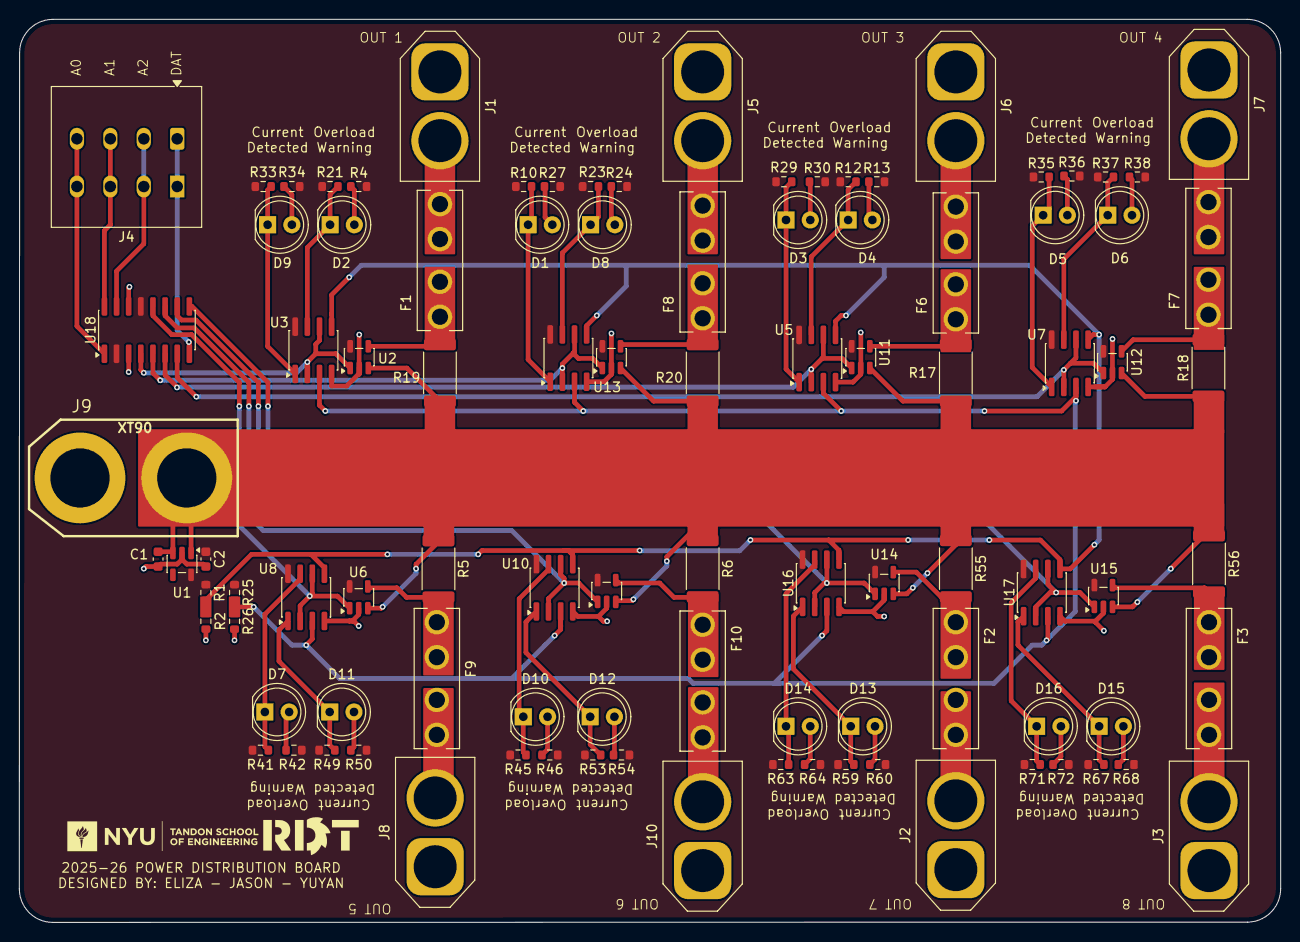
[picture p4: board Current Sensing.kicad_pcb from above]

Board: 2 copper layers, 132.0 x 94.5 mm, 98 parts (0 on the bottom side), 65 nets.

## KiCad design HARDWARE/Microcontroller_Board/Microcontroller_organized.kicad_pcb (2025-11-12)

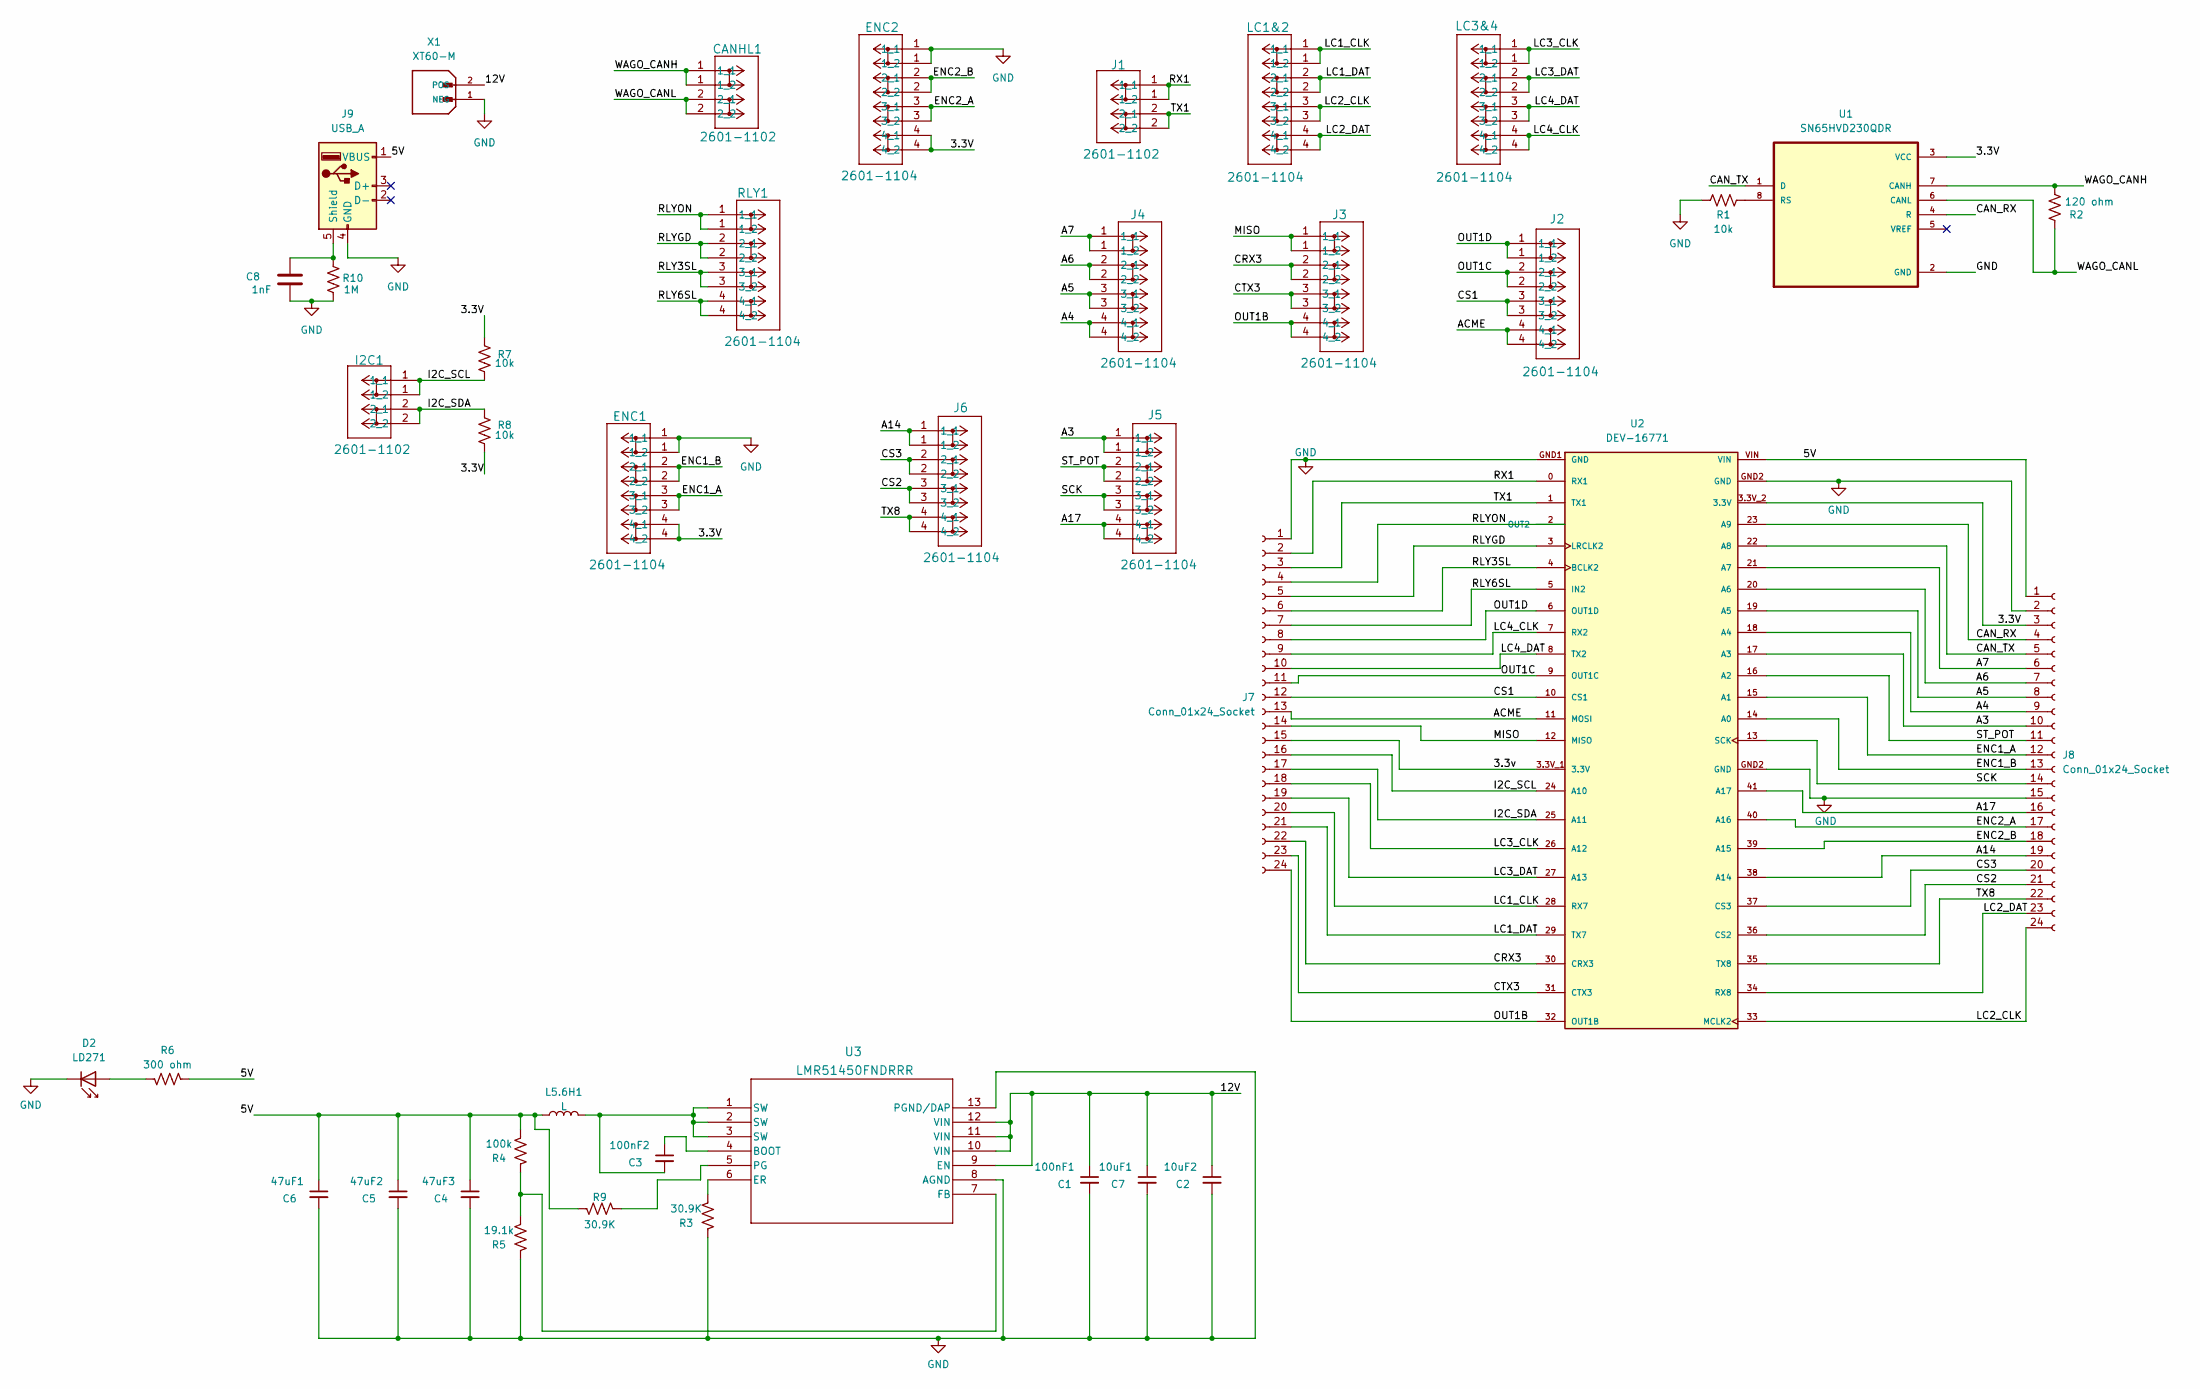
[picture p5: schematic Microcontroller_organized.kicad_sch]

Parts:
C1: 100nF1; C_0402_1005Metric_Pad0.74x0.62mm_HandSolder
C2: 10uF2; C_1206_3216Metric_Pad1.33x1.80mm_HandSolder
C3: 100nF2; C_0402_1005Metric_Pad0.74x0.62mm_HandSolder
C4: 47uF3; C_1210_3225Metric_Pad1.33x2.70mm_HandSolder
C5: 47uF2; C_1210_3225Metric_Pad1.33x2.70mm_HandSolder
C6: 47uF1; C_1210_3225Metric_Pad1.33x2.70mm_HandSolder
C7: 10uF1; C_1210_3225Metric_Pad1.33x2.70mm_HandSolder
C8: 1nF; C_0805_2012Metric_Pad1.18x1.45mm_HandSolder
CANHL1: 2601-1102; CONN2_2601-1102_WAG
D2: LD271; LED_D5.0mm
ENC1, ENC2: 2601-1104; CONN4_2601-1104_WAG
I2C1: 2601-1102; CONN2_2601-1102_WAG
J1: 2601-1102; CONN2_2601-1102_WAG
J2, J3, J4, J5, J6: 2601-1104; CONN4_2601-1104_WAG
J7, J8: Conn_01x24_Socket; PinHeader_1x24_P2.54mm_Vertical
J9: USB_A; USB_A_Receptacle_GCT_USB1046
L5.6H1: L; IND_IHLM-2525CZ_VIS-M
LC1&2, LC3&4: 2601-1104; CONN4_2601-1104_WAG
R1, R7, R8: 10k; R_0805_2012Metric
R2: 120 ohm; R_0805_2012Metric
R3, R9: 30.9K; R_0805_2012Metric
R4: 100k; R_0805_2012Metric
R5: 19.1k; R_0805_2012Metric
R6: 300 ohm; R_0805_2012Metric
R10: 1M; R_0805_2012Metric_Pad1.20x1.40mm_HandSolder
RLY1: 2601-1104; CONN4_2601-1104_WAG
U1: SN65HVD230QDR; SOIC127P599X175-8N
U2: DEV-16771; teensy4.1
U3: LMR51450FNDRRR; WSON_SDRRR_TEX
X1: XT60-M; AMASS_XT60-M; PARTREV V1.2

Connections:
/3.3V: ENC1.4 (4_1), ENC2.4 (4_1), J8.3, R7.2, R8.2, U1.3 (VCC), U2.3.3V_2 (3.3V)
/3.3v: J7.15, U2.3.3V_1 (3.3V)
/5V: C4.1, C5.1, C6.1, J8.1, J9.1 (VBUS), L5.6H1.2, R4.2, R6.2, R9.2, U2.VIN
/12V: C1.1, C2.1, C7.1, U3.9 (EN), U3.10 (VIN), U3.11 (VIN), U3.12 (VIN), X1.2 (POS)
/A3: J5.1 (1_1), J8.10, U2.17 (A3)
/A4: J4.4 (4_1), J8.9, U2.18 (A4)
/A5: J4.3 (3_1), J8.8, U2.19 (A5)
/A6: J4.2 (2_1), J8.7, U2.20 (A6)
/A7: J4.1 (1_1), J8.6, U2.21 (A7)
/A14: J6.1 (1_1), J8.19, U2.38 (A14)
/A17: J5.4 (4_1), J8.16, U2.41 (A17)
/ACME: J2.4 (4_1), J7.13, U2.11 (MOSI)
/CAN_RX: J8.4, U1.4 (R), U2.23 (A9)
/CAN_TX: J8.5, U1.1 (D), U2.22 (A8)
/CRX3: J3.2 (2_1), J7.22, U2.30 (CRX3)
/CS1: J2.3 (3_1), J7.12, U2.10 (CS1)
/CS2: J6.3 (3_1), J8.21, U2.36 (CS2)
/CS3: J6.2 (2_1), J8.20, U2.37 (CS3)
/CTX3: J3.3 (3_1), J7.23, U2.31 (CTX3)
/ENC1_A: ENC1.3 (3_1), J8.12, U2.15 (A1)
/ENC1_B: ENC1.2 (2_1), J8.13, U2.14 (A0)
/ENC2_A: ENC2.3 (3_1), J8.17, U2.40 (A16)
/ENC2_B: ENC2.2 (2_1), J8.18, U2.39 (A15)
/I2C_SCL: I2C1.1 (1_1), J7.16, R7.1, U2.24 (A10)
/I2C_SDA: I2C1.2 (2_1), J7.17, R8.1, U2.25 (A11)
/LC1_CLK: J7.20, LC1&2.1 (1_1), U2.28 (RX7)
/LC1_DAT: J7.21, LC1&2.2 (2_1), U2.29 (TX7)
/LC2_CLK: J8.24, LC1&2.3 (3_1), U2.33 (MCLK2)
/LC2_DAT: J8.23, LC1&2.4 (4_1), U2.34 (RX8)
/LC3_CLK: J7.18, LC3&4.1 (1_1), U2.26 (A12)
/LC3_DAT: J7.19, LC3&4.2 (2_1), U2.27 (A13)
/LC4_CLK: J7.9, LC3&4.4 (4_1), U2.7 (RX2)
/LC4_DAT: J7.10, LC3&4.3 (3_1), U2.8 (TX2)
/MISO: J3.1 (1_1), J7.14, U2.12 (MISO)
/OUT1B: J3.4 (4_1), J7.24, U2.32 (OUT1B)
/OUT1C: J2.2 (2_1), J7.11, U2.9 (OUT1C)
/OUT1D: J2.1 (1_1), J7.8, U2.6 (OUT1D)
/RLY3SL: J7.6, RLY1.3 (3_1), U2.4 (BCLK2)
/RLY6SL: J7.7, RLY1.4 (4_1), U2.5 (IN2)
/RLYGD: J7.5, RLY1.2 (2_1), U2.3 (LRCLK2)
/RLYON: J7.4, RLY1.1 (1_1), U2.2 (OUT2)
/RX1: J1.1 (1_1), J7.2, U2.0 (RX1)
/SCK: J5.3 (3_1), J8.14, U2.13 (SCK)
/ST_POT: J5.2 (2_1), J8.11, U2.16 (A2)
/TX1: J1.2 (2_1), J7.3, U2.1 (TX1)
/TX8: J6.4 (4_1), J8.22, U2.35 (TX8)
/WAGO_CANH: CANHL1.1 (1_1), R2.2, U1.7 (CANH)
/WAGO_CANL: CANHL1.2 (2_1), R2.1, U1.6 (CANL)
GND: C1.2, C2.2, C4.2, C5.2, C6.2, C7.2, C8.2, D2.1 (K), ENC1.1 (1_1), ENC2.1 (1_2), J7.1, J8.2, J8.15, J9.4 (GND), R1.1, R3.1, R5.1, R10.2, U1.2 (GND), U2.GND1 (GND), U2.GND2 (GND), U3.8 (AGND), U3.13 (PGND/DAP), X1.1 (NEG)
unnamed: C3.2, L5.6H1.1, U3.1 (SW), U3.2 (SW), U3.3 (SW)
unnamed: D2.2 (A), R6.1
unnamed: C8.1, J9.5 (Shield), R10.1
unnamed: R1.2, U1.8 (RS)
unnamed: C3.1, U3.4 (BOOT)
unnamed: R3.2, U3.6 (ER)
unnamed: R4.1, R5.2, U3.7 (FB)
unnamed: R9.1, U3.5 (PG)

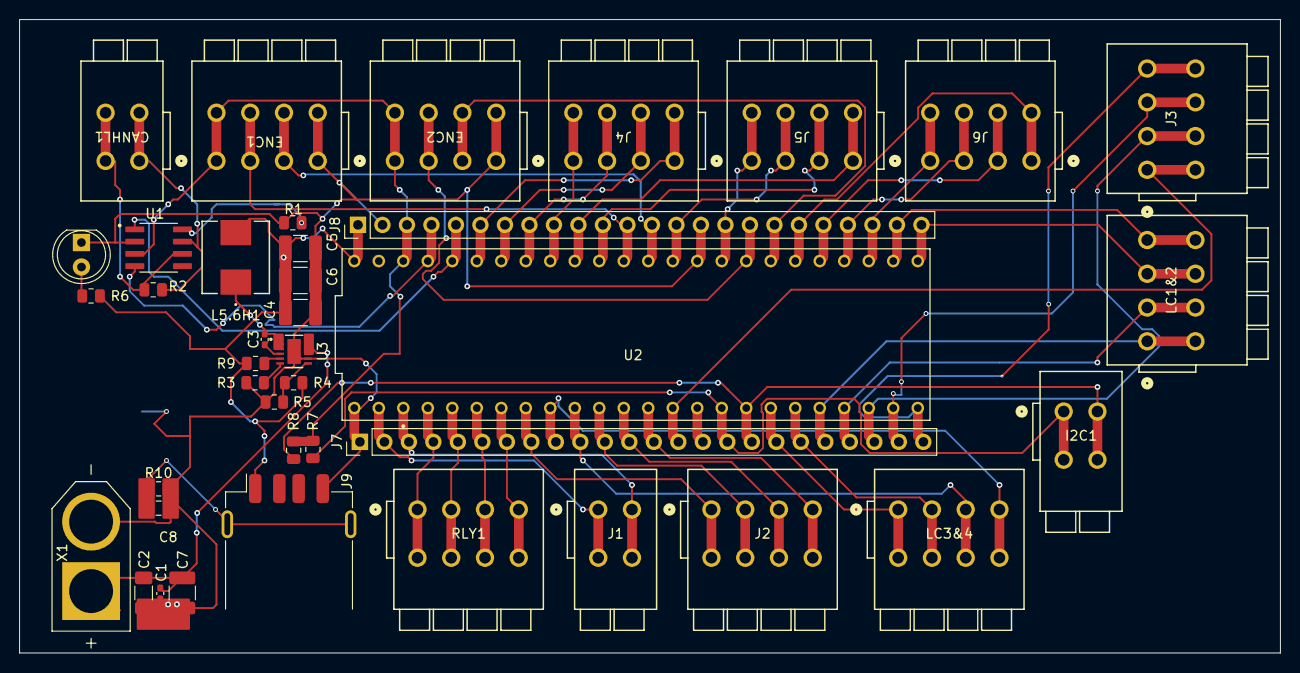
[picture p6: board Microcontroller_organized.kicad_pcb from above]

Board: 2 copper layers, 130.7 x 65.7 mm, 40 parts (0 on the bottom side), 57 nets.

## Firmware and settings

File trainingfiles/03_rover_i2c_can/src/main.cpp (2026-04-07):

/*
 * 03_rover_i2c_can — Minimal rover firmware with FreeRTOS
 * =========================================================
 * Goal: A real working rover firmware in ~300 lines. Everything the original
 * RDT_2025_26_TEENSY4_1 superloop does, but in three concurrent tasks:
 *
 *   TaskI2CDecode  (priority 3) — decodes commands from the I2C queue,
 *                                 builds MotorCommand_t structs, posts to xQueueMotor
 *   TaskMotorCtrl  (priority 2) — 20ms loop; slews speed toward target; sends CAN
 *   TaskEStop      (priority 5) — 10ms loop; monitors E-stop pin;
 *                                 sends direct task notification to bypass the queue
 *
 * The key difference vs the superloop (child_update):
 *   - E-stop is guaranteed to fire within one 10ms tick regardless of what
 *     the motor or command task is doing. In the superloop a long CAN write
 *     could delay E-stop processing.
 *   - Commands don't block the motor slew loop. A slow I2C burst doesn't
 *     cause a missed 20ms CAN cycle.
 *
 * New concepts vs project 02:
 *   ISR-safe queue send    — I2C callback can't use normal RTOS calls
 *   xQueueSendFromISR()    — the ISR-safe version; sets woken flag
 *   portYIELD_FROM_ISR()   — requests a context switch at ISR exit if needed
 *   Task notifications     — lighter-weight than a queue for a single flag
 *   xTaskNotify()          — send a notification value directly to a task handle
 *   xTaskNotifyWait()      — receive a notification (non-blocking here, poll)
 *   vTaskDelayUntil()      — precise periodic execution (vs vTaskDelay drift)
 */

#include <Arduino.h>
#include <Wire.h>
#include <FlexCAN_T4.h>
#include <climits>
#include "FreeRTOS.h"
#include "task.h"
#include "queue.h"
#include "semphr.h"
#include "config.h"

// ── Types ────────────────────────────────────────────────────────────────────

// A single decoded command posted from I2CDecode to MotorCtrl.
typedef struct {
    float leftSpeed;    // +1.0 = full forward, -1.0 = full reverse, 0 = stop
    float rightSpeed;
    float excavSpeed;
    bool  stopAll;      // E-stop or GRP_CONTROL stop — zero everything
    bool  hasLocoCmd;   // true if this command targets locomotion (including stop)
    bool  hasExcavCmd;  // true if this command targets excavation (including stop)
} MotorCommand_t;

// ── IPC handles ──────────────────────────────────────────────────────────────
static QueueHandle_t    xQueueI2C   = NULL;   // raw bytes from Wire2 ISR
static QueueHandle_t    xQueueMotor = NULL;   // decoded MotorCommand_t structs
static SemaphoreHandle_t xMutexCAN  = NULL;   // guards can1.write() calls
static TaskHandle_t     hTaskMotor  = NULL;   // handle for direct E-stop notification

// ── CAN bus ──────────────────────────────────────────────────────────────────
static FlexCAN_T4<CAN1, RX_SIZE_256, TX_SIZE_16> can1;

static void CAN_SendMotorSpeed(uint32_t id, float speed) {
#if SIMULATE_CAN
    // Skip real CAN write — without termination/ACK the controller goes bus-off
    // and the resulting error-interrupt storm starves all RTOS tasks.
    
#else
    CAN_message_t msg;
    msg.flags.extended = 1;
    msg.id  = id;
    msg.len = 4;
    // Speed is encoded as int32 × 100000, big-endian.
    int32_t val = (int32_t)(speed * 100000.0f);
    msg.buf[0] = (val >> 24) & 0xFF;
    msg.buf[1] = (val >> 16) & 0xFF;
    msg.buf[2] = (val >>  8) & 0xFF;
    msg.buf[3] =  val        & 0xFF;
    can1.write(msg);
#endif
}

// ── I2C ISR callbacks ─────────────────────────────────────────────────────────
// IMPORTANT: These run at interrupt level. Rules:
//   1. No blocking calls (no delay, no Serial, no xQueueSend with timeout > 0)
//   2. Only use *FromISR variants of RTOS calls
//   3. Declare woken, pass it in, call portYIELD_FROM_ISR at the end

static void I2C_OnReceive(int numBytes) {
    BaseType_t woken = pdFALSE;

    while (Wire2.available()) {
        uint8_t byte = Wire2.read();
        // xQueueSendFromISR never blocks — if the queue is full, it returns
        // pdFALSE and we silently drop the byte. That's acceptable: the
        // decode task should drain the queue faster than bytes arrive.
        xQueueSendFromISR(xQueueI2C, &byte, &woken);
    }

    // If sending woke a higher-priority task, yield to it immediately at
    // ISR exit instead of returning to whatever was preempted.
    portYIELD_FROM_ISR(woken);
}

// ── TaskI2CDecode ─────────────────────────────────────────────────────────────
// Decodes raw command bytes into MotorCommand_t and posts to the motor queue.
// This keeps all the command logic out of the ISR.
void TaskI2CDecode(void *pvParams) {
    uint8_t        raw;
    MotorCommand_t cmd;

    for (;;) {
        // Block until a byte arrives from the I2C ISR.
        if (xQueueReceive(xQueueI2C, &raw, portMAX_DELAY) != pdTRUE) {
            continue;
        }

        uint8_t group = CMD_GROUP(raw);
        uint8_t param = CMD_PARAM(raw);

        // Reset command to zero; only set what this group changes.
        memset(&cmd, 0, sizeof(cmd));

        switch (group) {
            case GRP_CONTROL:
                cmd.stopAll = true;
                break;

            case GRP_LOCO_STOP:
                cmd.hasLocoCmd = true;  // speeds stay 0 — stops locomotion only
                break;

            case GRP_FORWARD:
                cmd.leftSpeed  = -getSpeed(param);  // left motor is mechanically reversed
                cmd.rightSpeed =  getSpeed(param);
                cmd.hasLocoCmd = true;
                break;

            case GRP_BACKWARD:
                cmd.leftSpeed  =  getSpeed(param);
                cmd.rightSpeed = -getSpeed(param);
                cmd.hasLocoCmd = true;
                break;

            case GRP_LEFT:
                // Turn left: both motors spin the same direction
                cmd.leftSpeed  = getSpeed(param);
                cmd.rightSpeed = getSpeed(param);
                cmd.hasLocoCmd = true;
                break;

            case GRP_RIGHT:
                cmd.leftSpeed  = -getSpeed(param);
                cmd.rightSpeed = -getSpeed(param);
                cmd.hasLocoCmd = true;
                break;

            case GRP_EXCAVATION:
                // Old mapping: params 0-2 = vertical stepper, params 3-5 = belt CAN
                if (param >= 3) {
                    cmd.excavSpeed  = getDirection(param - 3) * EXCAVATION_DUTY_CYCLE;
                    cmd.hasExcavCmd = true;
                } else {
                    Serial.println("[I2CDecode] excav vert not implemented");
                }
                break;

            case GRP_DEPOSITION:
                Serial.println("[I2CDecode] deposition not implemented");
                break;

            default:
                // Unknown group — ignore
                continue;
        }

        // Post to motor queue; wait up to 5ms. If it's full something is wrong
        // (motor task not running?) — drop the command rather than stall decode.
        if (xQueueSend(xQueueMotor, &cmd, pdMS_TO_TICKS(5)) != pdTRUE) {
            Serial.println("[I2CDecode] WARNING: motor queue full");
        }
    }
}

// ── TaskMotorCtrl ─────────────────────────────────────────────────────────────
// Runs every TX_PERIOD_MS. Drains the motor queue for the latest command,
// slews speed toward the target, then sends CAN. Also handles command timeout.
void TaskMotorCtrl(void *pvParams) {
    float currentLeft  = 0.0f;
    float currentRight = 0.0f;
    float currentExcav = 0.0f;
    float targetLeft   = 0.0f;
    float targetRight  = 0.0f;
    float targetExcav  = 0.0f;

    uint32_t lastCmdTime = millis();
    MotorCommand_t cmd;
    TickType_t lastWake = xTaskGetTickCount();

    for (;;) {
        // ── 1. Check for E-stop notification ──────────────────────────────
        // xTaskNotifyWait with 0 timeout = non-blocking poll.
        // TaskEStop sends notification value 1 on assert, 0 on release.
        // We check this FIRST every cycle so the hard stop takes effect even
        // if a command also arrived this tick.
        uint32_t notifyVal = 0;
        if (xTaskNotifyWait(0, ULONG_MAX, &notifyVal, 0) == pdTRUE) {
            if (notifyVal == 1U) {
                // E-stop asserted: zero everything, clear the motor queue
                targetLeft = targetRight = targetExcav = 0.0f;
                while (xQueueReceive(xQueueMotor, &cmd, 0) == pdTRUE) {}
                Serial.println("[MotorCtrl] E-STOP: motors zeroed");
            }
            // notifyVal == 0 means released — SW can send new commands freely
        }

        // ── 2. Drain motor queue for latest command ────────────────────────
        // We drain the whole queue and keep only the last item. This means if
        // multiple commands arrived in one 20ms window we act on the most recent.
        bool gotCmd = false;
        while (xQueueReceive(xQueueMotor, &cmd, 0) == pdTRUE) {
            gotCmd = true;
        }
        if (gotCmd) {
            lastCmdTime = millis();
            if (cmd.stopAll) {
                targetLeft = targetRight = targetExcav = 0.0f;
            } else {
                // Only update targets that the command actually addresses.
                // Locomotion commands leave excavation unchanged, and vice versa.
                if (cmd.hasLocoCmd) {
                    targetLeft  = cmd.leftSpeed;
                    targetRight = cmd.rightSpeed;
                }
                if (cmd.hasExcavCmd) {
                    targetExcav = cmd.excavSpeed;
                }
            }
        }

        // ── 3. Command timeout ─────────────────────────────────────────────
        // If no command has arrived for COMMAND_TIMEOUT_MS, stop motors.
        // Prevents runaway if the Jetson crashes or the I2C cable comes loose.
        if ((millis() - lastCmdTime) > (uint32_t)COMMAND_TIMEOUT_MS) {
            targetLeft = targetRight = targetExcav = 0.0f;
        }

        // ── 4. Slew toward target ──────────────────────────────────────────
        // Instead of jumping to the target speed instantly, ramp at
        // MAX_SPEED_DELTA_PER_TICK per cycle. This prevents current spikes
        // and jerk on the drivetrain.
        auto slew = [](float cur, float tgt) -> float {
            float delta = tgt - cur;
            if (delta >  MAX_SPEED_DELTA_PER_TICK) delta =  MAX_SPEED_DELTA_PER_TICK;
            if (delta < -MAX_SPEED_DELTA_PER_TICK) delta = -MAX_SPEED_DELTA_PER_TICK;
            return cur + delta;
        };
        currentLeft  = slew(currentLeft,  targetLeft);
        currentRight = slew(currentRight, targetRight);
        currentExcav = slew(currentExcav, targetExcav);

        // ── 5. Send CAN ────────────────────────────────────────────────────
        // Mutex guards the CAN peripheral — in the full firmware the anomaly
        // task also writes CAN, so we need this even in the simplified version.
        if (xSemaphoreTake(xMutexCAN, pdMS_TO_TICKS(5)) == pdTRUE) {
            CAN_SendMotorSpeed(CAN_ID_LEFT_MOTOR,       currentLeft);
            CAN_SendMotorSpeed(CAN_ID_RIGHT_MOTOR,      currentRight);
            CAN_SendMotorSpeed(CAN_ID_EXCAVATION_MOTOR, currentExcav);
            xSemaphoreGive(xMutexCAN);
        }

#if PRINT_CAN
        // Print all three speeds together, throttled so Serial isn't flooded.
        // The motor loop runs every TX_PERIOD_MS (20ms) — without throttling
        // that's 150 lines/s. CAN_PRINT_PERIOD_MS in config.h controls the rate.
        static uint32_t lastCanPrint = 0;
        uint32_t nowMs = millis();
        if (nowMs - lastCanPrint >= (uint32_t)CAN_PRINT_PERIOD_MS) {
            lastCanPrint = nowMs;
            Serial.printf("[CAN] L=% .3f  R=% .3f  E=% .3f\n",
                          currentLeft, currentRight, currentExcav);
        }
#endif

        // ── 6. Wait until next 20ms tick ──────────────────────────────────
        // vTaskDelayUntil is preferred over vTaskDelay for periodic tasks.
        // vTaskDelay(20) would drift by execution time each cycle.
        // vTaskDelayUntil wakes at lastWake + 20ms regardless of how long
        // steps 1-5 took (as long as they finished within 20ms).
        vTaskDelayUntil(&lastWake, pdMS_TO_TICKS(TX_PERIOD_MS));
    }
}

// ── TaskEStop ─────────────────────────────────────────────────────────────────
// Highest priority task. Two responsibilities:
//   1. Continuously drives E_STOP_RELAY_DRIVE_PIN HIGH (fail-safe relay).
//      If this task ever stops running the pin goes LOW and cuts motor power.
//   2. Watches E_STOP_READ_PIN for an asserted (LOW) E-stop signal and
//      notifies the motor task to stop immediately — bypassing the command queue.
//
// WHY BYPASS THE QUEUE?
//   The motor queue might have a bunch of speed commands waiting to execute.
//   If we posted a "stop" command to the back of the queue the motors would
//   execute all the earlier commands first. Task notifications go directly
//   to the motor task and are checked at the TOP of every 20ms cycle, before
//   any queued commands are processed.
void TaskEStop(void *pvParams) {
    bool     prevAsserted = false;
    bool     prevPinLow   = false;   // tracks last pin state to detect edges
    uint32_t assertedSince = 0;

    for (;;) {
        // Keep the relay coil energised — this is the fail-safe.
        digitalWrite(E_STOP_RELAY_DRIVE_PIN, HIGH);

        bool pinLow = (digitalRead(E_STOP_READ_PIN) == LOW);

        // Start the debounce timer only on the HIGH→LOW edge, not every tick.
        // Bug if you use (pinLow && !prevAsserted): prevAsserted stays false until
        // debounce fires, so the timer resets every 10ms loop and never accumulates.
        if (pinLow && !prevPinLow) {
            assertedSince = millis();
        }
        prevPinLow = pinLow;

        bool debounced = pinLow && ((millis() - assertedSince) >= ESTOP_DEBOUNCE_MS);

        if (debounced && !prevAsserted) {
            prevAsserted = true;
            Serial.println("[EStop] ASSERTED");
            // Notification value 1 = stop. The motor task checks this each cycle.
            xTaskNotify(hTaskMotor, 1U, eSetValueWithOverwrite);
        } else if (!pinLow && prevAsserted) {
            prevAsserted = false;
            Serial.println("[EStop] released");
            // Notification value 0 = released — motor task can accept commands again.
            xTaskNotify(hTaskMotor, 0U, eSetValueWithOverwrite);
        }

        // Periodic status line so you can confirm pin state without waiting for a
        // transition. Fires at CAN_PRINT_PERIOD_MS so it lines up with the CAN print.
        static uint32_t lastEstopPrint = 0;
        uint32_t nowEstop = millis();
        if (nowEstop - lastEstopPrint >= (uint32_t)CAN_PRINT_PERIOD_MS) {
            lastEstopPrint = nowEstop;
            Serial.printf("[EStop] pin=%s  debounced=%s  asserted=%s\n",
                          pinLow      ? "LOW " : "HIGH",
                          debounced   ? "YES"  : "no",
                          prevAsserted? "YES"  : "no");
        }

        vTaskDelay(pdMS_TO_TICKS(10));
    }
}

// ── setup() ──────────────────────────────────────────────────────────────────
void setup() {
    Serial.begin(115200);
    while (!Serial && millis() < 3000) {}

    // Energise relay immediately — before the scheduler starts — so that
    // even a crash in setup() doesn't leave the relay in an unknown state.
    pinMode(E_STOP_RELAY_DRIVE_PIN, OUTPUT);
    digitalWrite(E_STOP_RELAY_DRIVE_PIN, HIGH);

    pinMode(E_STOP_READ_PIN, INPUT_PULLDOWN);

    Serial.println("=== 03_rover_i2c_can ===");

    // CAN init must come before tasks that write CAN
    can1.begin();
    can1.setBaudRate(CAN_BAUD_RATE);

    // Create IPC primitives before any task or ISR that uses them.
    // Depths are set in config.h — see experiment A and B.
    xQueueI2C   = xQueueCreate(I2C_QUEUE_DEPTH,   sizeof(uint8_t));
    xQueueMotor = xQueueCreate(MOTOR_QUEUE_DEPTH,  sizeof(MotorCommand_t));
    xMutexCAN   = xSemaphoreCreateMutex();
    configASSERT(xQueueI2C   != NULL);
    configASSERT(xQueueMotor != NULL);
    configASSERT(xMutexCAN   != NULL);

    // Register I2C callbacks AFTER queues exist (callbacks use xQueueI2C)
    Wire2.begin(I2C_CHILD_ADDRESS);
    Wire2.onReceive(I2C_OnReceive);

    // Create tasks.
    // Motor task is created first so hTaskMotor is valid before EStop starts.
    // Stack sizes are set in config.h — see experiment F.
    configASSERT(xTaskCreate(TaskMotorCtrl,  "MotorCtrl",  MOTOR_TASK_STACK,  NULL, 2, &hTaskMotor) == pdPASS);
    configASSERT(xTaskCreate(TaskI2CDecode,  "I2CDecode",  DECODE_TASK_STACK, NULL, 3, NULL)        == pdPASS);
    configASSERT(xTaskCreate(TaskEStop,      "EStop",      ESTOP_TASK_STACK,  NULL, 5, NULL)        == pdPASS);

    Serial.println("Tasks created. Starting scheduler.");
    vTaskStartScheduler();

    Serial.println("ERROR: scheduler exited — halt.");
    while (true) {}
}

void loop() {}

// freertos-teensy provides default vApplicationStackOverflowHook and
// vApplicationMallocFailedHook implementations. See 01_blink_rtos for notes.

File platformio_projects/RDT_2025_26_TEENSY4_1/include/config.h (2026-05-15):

#pragma once
#include <stdint.h>
#include "pins.h"

// ── Feature flags ─────────────────────────────────────────────────────────────
#define RAMP_UP        1
#define SERIAL_DEBUG   0
// PLOT_DATA outputs sensor data in Teleplot format (>name:value).
// Mutually exclusive with SERIAL_DEBUG — enabling both corrupts the plotter stream.
#define PLOT_DATA      1
#define PLOT_PERIOD_MS 50
#define USE_TIMEOUT    1
#define ANALOG_VIB_CONTROL 0
#define USE_OLD_HEX_MAPPING 1

// ── Sensor enable flags ───────────────────────────────────────────────────────
// Set ALL_SENSORS_ENABLED=1 to enable everything at once (bring-up only).
#define ALL_SENSORS_ENABLED 0

#if ALL_SENSORS_ENABLED
    #define CURRENT_SENSE_ENABLED   1
    #define ROTARY_ENCODERS_ENABLED 1
    #define LOAD_CELLS_ENABLED      1
    #define STRING_POT_ENABLED      1
    #define GATE_POS_ENABLED        1
#else
    #define CURRENT_SENSE_ENABLED   1
    #define ROTARY_ENCODERS_ENABLED 1
    #define LOAD_CELLS_ENABLED      0
    #define STRING_POT_ENABLED      1
    #define GATE_POS_ENABLED        1
#endif

// ── I2C ───────────────────────────────────────────────────────────────────────
#define I2C_CHILD_ADDRESS  0x08
#define COMMAND_TIMEOUT_MS 500
// Size of the SW telemetry packet. Must match SW expectation.
// Unimplemented sensors send 0xFF as a sentinel.
#define DATA_PACKET_SIZE 18

// ── CAN bus ───────────────────────────────────────────────────────────────────
#define CAN_BAUD_RATE           500000
#define CAN_ID_LEFT_MOTOR       0x4C
#define CAN_ID_RIGHT_MOTOR      0x78
#define CAN_ID_EXCAVATION_MOTOR 0x48 // VERIFY — may need update

// ── Locomotion ────────────────────────────────────────────────────────────────
#define LOCOMOTION_DUTY_CYCLE       0.33f
#define LOCOMOTION_DUTY_CYCLE_EXCAV 0.1f  // reduced cap while belt is spinning
#define TX_PERIOD_MS                20
#define MAX_SPEED_DELTA_PER_TICK    0.01f

// ── Excavation ────────────────────────────────────────────────────────────────
#define EXCAVATION_DUTY_CYCLE       0.6f // prev: 0.4f
#define MAX_EXCAV_DELTA_PER_TICK    0.01f
// ~900 µs is the no-load speed limit (established by stepper_test).
// 1000 µs gives margin; tune down toward 900 µs only after verifying reliable
// start under full mechanical load.
#define EXCAVATION_STEP_PERIOD_DOWN 1500  // µs full step period descending (slower — active dig)
#define EXCAVATION_STEP_PERIOD_UP   1050  // µs full step period ascending (faster — recovery)

#define STEPS_PER_REVOLUTION        200   // full-step count
#define MICROSTEPPING_FACTOR        1     // 1, 2, 4, 8, 16, or 32


// String pot calibration — board-specific, tune after physical testing
#define STRING_POT_SCALE            37.125f
#define STRING_POT_OFFSET           -3.511f
#define STRING_POT_MAX_RAW          1023.0f
#define STRING_POT_MAX_DISTANCE     ((STRING_POT_SCALE * 3.3f) - STRING_POT_OFFSET)
#define STRING_POT_LOWEST_THRESHOLD  13.0f
#define STRING_POT_HIGHEST_THRESHOLD 31.0f
#define STRING_MOVING 0
#define STRING_LOWEST 1
#define STRING_HIGHEST 2
#define STRING_MIDDLE 3

// ── Load cells ────────────────────────────────────────────────────────────────
#define NUM_LOAD_CELLS               4
#define LOAD_CELL_SCALE              1.0f   // TODO: calibrate (raw → kg)
#define LOAD_CELL_EMPTY_THRESHOLD_KG 0.1f  // TODO: tune — bin empty below this

// ── Telemetry flag thresholds ─────────────────────────────────────────────────
// Current channel map: 0=left loco, 1=right loco, 2=vib, 3=depo door, 4=stepper, 5=excav belt
#define CURRENT_LOCO_STALL_A         0.0f  // TODO: measure — loco stall current
#define CURRENT_STEPPER_OBSTRUCT_A   0.0f  // TODO: measure — stepper obstruction spike
#define CURRENT_EXCAV_EMPTY_CUT_A    0.0f  // TODO: measure — belt current at empty cut
#define CURRENT_EXCAV_STALL_A        0.0f  // TODO: measure — belt stall current
#define CURRENT_OVERCURRENT_ANY_A    0.0f  // TODO: measure — max safe current any channel
#define EXCAV_EMPTY_CUT_PERSIST_MS   500   // belt must be below threshold this long before flagging
#define EXCAV_STALL_MASS_DELTA_KG    0.05f // min mass gain expected per stall window
#define EXCAV_STALL_WINDOW_MS        2000  // time window for excav stall mass-flow check
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

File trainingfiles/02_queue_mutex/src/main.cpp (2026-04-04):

/*
 * 02_queue_mutex — Queues and Mutexes
 * =====================================
 * Goal: Show the two most important inter-task communication tools.
 *
 * Three tasks:
 *   TaskProducer  — sends an incrementing counter to a queue every 500 ms
 *   TaskConsumer  — blocks on the queue; prints each value it receives
 *   TaskPrinter   — every 2 s prints a status line, protected by a mutex
 *
 * WHY A QUEUE?
 *   Passing data between tasks via a global variable is unsafe — the compiler
 *   can cache it in a register, and one task can read a half-written value
 *   if the other task is preempted mid-write. A queue copies the data atomically
 *   and wakes the consumer only when data is ready. No polling, no races.
 *
 * WHY A MUTEX?
 *   Serial.print is not thread-safe. If TaskProducer and TaskPrinter both call
 *   Serial.print at the same moment, their output bytes interleave into garbage.
 *   A mutex lets only one task into the Serial section at a time. Take → print
 *   → give, every time.
 *
 * New concepts vs project 01:
 *   xQueueCreate()         — allocate a queue of N items of a given size
 *   xQueueSend()           — post an item (blocks if queue is full)
 *   xQueueReceive()        — pop an item (blocks until one arrives)
 *   xSemaphoreCreateMutex() — allocate a mutual-exclusion lock
 *   xSemaphoreTake()       — acquire the lock (blocks if held by another task)
 *   xSemaphoreGive()       — release the lock
 */

#include <Arduino.h>
#include "FreeRTOS.h"
#include "task.h"
#include "queue.h"
#include "semphr.h"
#include "config.h"

// ── Shared IPC handles ───────────────────────────────────────────────────────
// Declare these at file scope so all tasks can reach them.
// They're just integer handles — the actual memory lives in the FreeRTOS heap.
static QueueHandle_t    xQueueCounter = NULL;
static SemaphoreHandle_t xMutexSerial = NULL;

// ── Helper: safe Serial print ────────────────────────────────────────────────
// Any task that wants to print should call this instead of Serial directly.
// The timeout (100 ms) prevents a stuck task from holding the mutex forever.
static void safePrint(const char *msg) {
    if (xSemaphoreTake(xMutexSerial, pdMS_TO_TICKS(100)) == pdTRUE) {
        Serial.print(msg);
        xSemaphoreGive(xMutexSerial);
    }
}

static void safePrintln(const char *msg) {
    if (xSemaphoreTake(xMutexSerial, pdMS_TO_TICKS(100)) == pdTRUE) {
        Serial.println(msg);
        xSemaphoreGive(xMutexSerial);
    }
}

// ── TaskProducer ─────────────────────────────────────────────────────────────
void TaskProducer(void *pvParams) {
    uint32_t counter = 0;
    char buf[64];

    for (;;) {
        counter++;

        // xQueueSend copies `counter` into the queue — not a pointer, the actual
        // value. This is important: the queue owns the data after this call,
        // so it's safe to modify `counter` immediately afterward.
        //
        // The last argument is the block time: how long to wait if the queue
        // is full. pdMS_TO_TICKS(0) = don't wait; drop the item if full.
        // We use 10 ms here so we don't stall production, but we won't silently
        // drop items under normal operation.
        if (xQueueSend(xQueueCounter, &counter, pdMS_TO_TICKS(10)) != pdTRUE) {
            safePrintln("[Producer] WARNING: queue full, item dropped");
        } else {
            snprintf(buf, sizeof(buf), "[Producer] sent: %lu", counter);
            safePrintln(buf);
        }

        vTaskDelay(pdMS_TO_TICKS(PRODUCER_PERIOD_MS));
    }
}

// ── TaskConsumer ─────────────────────────────────────────────────────────────
void TaskConsumer(void *pvParams) {
    uint32_t received;
    char buf[64];

    for (;;) {
        // xQueueReceive blocks indefinitely (portMAX_DELAY) until an item
        // arrives. This task consumes 0 CPU while waiting — much better than
        // a polling loop with a delay inside.
        if (xQueueReceive(xQueueCounter, &received, portMAX_DELAY) == pdTRUE) {
            snprintf(buf, sizeof(buf), "[Consumer] received: %lu", received);
            safePrintln(buf);

            // Blink LED to give a visual indication of activity.
            digitalWrite(LED_BUILTIN, !digitalRead(LED_BUILTIN));

            // CONSUMER_SLOW_MS > 0 throttles the consumer so the queue fills up.
            // See config.h experiment A.
            if (CONSUMER_SLOW_MS > 0) {
                vTaskDelay(pdMS_TO_TICKS(CONSUMER_SLOW_MS));
            }
        }
    }
}

// ── TaskPrinter ───────────────────────────────────────────────────────────────
// Lower priority status task — runs every 2 s and prints heap/queue info.
// Demonstrates that the mutex also keeps this task's multi-line output intact.
void TaskPrinter(void *pvParams) {
    char buf[128];

    for (;;) {
        vTaskDelay(pdMS_TO_TICKS(PRINTER_PERIOD_MS));

        // Take the mutex before the entire multi-line block.
        // Without this, Consumer's single-line prints could interleave here.
        if (xSemaphoreTake(xMutexSerial, pdMS_TO_TICKS(200)) == pdTRUE) {
            Serial.println("---- status ----");
            snprintf(buf, sizeof(buf),
                     "  free heap:    %u bytes", xPortGetFreeHeapSize());
            Serial.println(buf);
            snprintf(buf, sizeof(buf),
                     "  queue waiting: %u items", uxQueueMessagesWaiting(xQueueCounter));
            Serial.println(buf);
            Serial.println("----------------");
            xSemaphoreGive(xMutexSerial);
        }
    }
}

// ── setup() ──────────────────────────────────────────────────────────────────
void setup() {
    Serial.begin(115200);
    while (!Serial && millis() < 3000) {}

    pinMode(LED_BUILTIN, OUTPUT);

    // Create the queue. QUEUE_DEPTH is set in config.h — reduce it to 1 to see
    // drops almost immediately; increase it to buffer large bursts.
    xQueueCounter = xQueueCreate(QUEUE_DEPTH, sizeof(uint32_t));
    configASSERT(xQueueCounter != NULL);

    // Create the mutex. A mutex starts in the "given" (unlocked) state.
    xMutexSerial = xSemaphoreCreateMutex();
    configASSERT(xMutexSerial != NULL);

    Serial.println("=== 02_queue_mutex ===");

    // Priority 2: Producer and Consumer are equal — they time-slice.
    // Priority 1: Printer is lower, runs only when the others are sleeping.
    // Stack size comes from config.h — change TASK_STACK_WORDS to see heap shift.
    configASSERT(xTaskCreate(TaskProducer, "Producer", TASK_STACK_WORDS, NULL, 2, NULL) == pdPASS);
    configASSERT(xTaskCreate(TaskConsumer, "Consumer", TASK_STACK_WORDS, NULL, 2, NULL) == pdPASS);
    configASSERT(xTaskCreate(TaskPrinter,  "Printer",  TASK_STACK_WORDS, NULL, 1, NULL) == pdPASS);

    vTaskStartScheduler();
    Serial.println("ERROR: scheduler exited — halt.");
    while (true) {}
}

void loop() {}
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

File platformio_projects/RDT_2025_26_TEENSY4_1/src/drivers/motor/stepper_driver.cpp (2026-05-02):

// Use the pwr/gnd rails on one side for the teensy and the other side for pwr supply with cap
// ENABLE and FAULT not wired
// M0 goes to pin 10, M1 to pin 11, M2 to pin 12
// Reset and Sleep go to power rail --> Teensy 5v
// Step goes to pin 7 and DIR goes to pin 6
// VMOT and GND go to 100E-6 cap on the other side pwr and gnd rails w power supply
// B2 to candy cane green on stepper, B1 to solid green, A1 to solid red, A2 to candy cane red
// GND to gnd rail duh
// Set pwr supply to ~12V

#include <Arduino.h>
#include "stepper_driver.h"
#include "config.h" 

static bool STEPPER_enable = false; // global variable to track if motor should be enabled
static unsigned long lastStepTime = 0; // track last step time for timing control, in microseconds
static bool isStepPinHigh = false; // track state of step pin for timing control

void STEPPER_Init() {
    pinMode(STEPPER_DIR_PIN, OUTPUT);
    pinMode(STEPPER_STEP_PIN, OUTPUT);
    pinMode(STEPPER_ENABLE_PIN, OUTPUT);
    pinMode(STEPPER_M0_PIN, OUTPUT);
    pinMode(STEPPER_M1_PIN, OUTPUT);
    pinMode(STEPPER_M2_PIN, OUTPUT);
    setMicrostep(MICROSTEPPING_FACTOR); 

    // Start with motor disabled
    digitalWrite(STEPPER_ENABLE_PIN, HIGH); // HIGH to disable
}

void setMicrostep(int mode) {
  // mode = 1, 2, 4, 8, 16, 32
  // set the step mode - full, 1/2, 1/4, 1/8, 1/16, or 1/32 step
  switch (mode) {
    case 1:   digitalWrite(STEPPER_M0_PIN, LOW);  digitalWrite(STEPPER_M1_PIN, LOW);  digitalWrite(STEPPER_M2_PIN, LOW);  break;
    case 2:   digitalWrite(STEPPER_M0_PIN, HIGH); digitalWrite(STEPPER_M1_PIN, LOW);  digitalWrite(STEPPER_M2_PIN, LOW);  break;
    case 4:   digitalWrite(STEPPER_M0_PIN, LOW);  digitalWrite(STEPPER_M1_PIN, HIGH); digitalWrite(STEPPER_M2_PIN, LOW);  break;
    case 8:   digitalWrite(STEPPER_M0_PIN, HIGH); digitalWrite(STEPPER_M1_PIN, HIGH); digitalWrite(STEPPER_M2_PIN, LOW);  break;
    case 16:  digitalWrite(STEPPER_M0_PIN, LOW);  digitalWrite(STEPPER_M1_PIN, LOW);  digitalWrite(STEPPER_M2_PIN, HIGH); break;
    case 32:  digitalWrite(STEPPER_M0_PIN, HIGH); digitalWrite(STEPPER_M1_PIN, LOW);  digitalWrite(STEPPER_M2_PIN, HIGH); break;
  }
}

// dir is 1 for up, -1 for down, 0 for stop
// enable stores if the motor should be on or not
// we set dirPin based on direction input, qhich directly controlls motor
void STEPPER_SetDirection(int direction) {
    // // S = (direction==0) ? false : true; // sets enable true if moving, false if stopped
    STEPPER_enable = (direction!=0);
    (STEPPER_enable) ? (digitalWrite(STEPPER_ENABLE_PIN, LOW)) : (digitalWrite(STEPPER_ENABLE_PIN, HIGH)); // enable must be HIGH when NOT moving
    if (direction == 1) { // UP — HIGH matches stepper_test bench convention
        digitalWrite(STEPPER_DIR_PIN, HIGH);
    } else if (direction == -1) { // DOWN
        digitalWrite(STEPPER_DIR_PIN, LOW);
    }
}

// call every loop to step, handles its own timing
// using micros so it doesnt have to stop the rest of the program 
// every period/2 it toggels the output, giving us a rising edge every period, which steps the motor
void STEPPER_Update(unsigned long periodMicroseconds) {
    if (STEPPER_enable) {
        unsigned long currentTime = micros();
        if (currentTime - lastStepTime >= periodMicroseconds/2) {
            isStepPinHigh = !isStepPinHigh; 
            digitalWrite(STEPPER_STEP_PIN, isStepPinHigh ? HIGH : LOW);
            lastStepTime = currentTime;
        }
    }
}

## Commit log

2025-10-12 Create Teensy4.1 KiCad Schematic
2025-10-12 added the KiCad schematic for the teensy
    [TEENSY4.1.kicad_pcb, TEENSY4.1.kicad_sch]
2025-10-13 Add files via upload
    Added the footprints
    [TEENSY4.1.kicad_sch]
2025-10-16 Add files via upload
    updated capacitors and microcontroller symbol
2025-10-27 added the new miccrocontorller schemtics
    [Microcontroller_Board.kicad_pcb, Microcontroller_Board.kicad_sch]
2025-11-05 motor test scripts
2025-11-11 finshied wiring pcb
    [Microcontroller_organized.kicad_pcb]
2025-11-11 got rid of some errors
    [Microcontroller_organized.kicad_pcb]
2025-11-12 shifted usb
    [Microcontroller_organized.kicad_pcb]
2026-01-27 moved estop and relay functions to new system file
2026-01-27 organized repo structure
    [Microcontroller_Board.kicad_pcb, Microcontroller_Board.kicad_sch, Microcontroller_organized.kicad_pcb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]
2026-02-14 Create Stepper_motor_DRV8825
    Code and wiring documentation used for testing DRV8825 Stepper Motor Driver
2026-02-14 added vib motor
    [VibMotor.kicad_pcb, VibMotor.kicad_sch]
2026-02-26 i2c teensy testing code for parent and child
2026-03-03 i2c parent and child with CAN commands
2026-03-06 Added first I2C master and CAN slave test projects
2026-03-11 can-i2c rebuilt with more embedded C features
2026-03-13 Replace GET_SPEED macro with self-contained inline function in config.h
    [child.cpp, config.h]
2026-03-13 Update Stepper_motor_DRV8825
2026-03-23 full testing setup for i2c-can
2026-03-23 moved things around to avoid clutter in test folder
    [CAN Slave Motor.cpp, I2C Master.cpp, can_driver.cpp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]
2026-03-23 moved i2ccan code to main project
2026-03-23 made a more robust testing setup - was control +i2c
2026-03-23 made a more robust testing setup (WASD +i2c)
2026-03-23 moved stepper to testing, improved docs
2026-03-23 organized files
    [VibMotor.kicad_pcb, VibMotor.kicad_sch]
2026-03-28 added linear actuator test
2026-03-28 integrated test stepper code into parent and child
2026-03-28 tried testing i2c with SW
2026-03-29 added depo door driver
2026-03-29 integrated depo door driver
2026-03-29 minot chnages to stepper drvier
    [2024-2025 Software & EE Hex Value Key - 2024-2025 Manual Control Actions.csv]
2026-03-29 depo vib motor driver
2026-03-30 fixed motor direction
2026-03-31 updated stepper code
2026-04-02 feat: add FreeRTOS training projects in trainingfiles/
    Three standalone PlatformIO projects for teaching team members RTOS
    concepts in increasing complexity:
    01_blink_rtos — xTaskCreate, vTaskDelay, concurrency basics
    02_queue_mutex — xQueueCreate/Send/Receive, xSemaphoreCreateMutex
    03_rover_i2c_can — ISR-safe I2C→queue→motor pipeline + E-stop notifications
    All three compile clean for teensy41 with -Wall.
2026-04-02 chore: add .pio/ to .gitignore and untrack build artifacts
    PlatformIO build output and downloaded library sources should not be
    version controlled — they are regenerated by pio run.
2026-04-02 published working Arduino Motor Test Code
2026-04-03 fix: fixed config setting for RTOS demos and updated the related README
    [main.cpp]
2026-04-03 fix: fiexed excavation unable to stop in demo 3 bug
    [main.cpp]
2026-04-03 feat: added relay board pins, reordered depo vib controls
2026-04-04 added basic data function, tested vib motor works
2026-04-04 fixed some bugs in demos and made them more interactive
    [config.h, main.cpp]
2026-04-07 tested rtos i2c-can
2026-04-08 added current sensing - needs more testing
2026-04-08 addressed issues in curent sensing
    [child.cpp, config.h, current_sensors.cpp]
2026-04-08 fix: adjusted adc scaling back in parent test
    [keyboard.cpp]
2026-04-08 chore: organized files, moved testing script to platofrmio_projects, and renamed to i2c_parent
2026-04-10 stub for sensor data
2026-04-10 feature: encoder logic, fix: added stepper enable pin logic
    [current_sensors.cpp, keyboard.cpp, rotary_encoders.cpp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]
2026-04-10 fix: adressed issues in rotary ecnoder implem based on code review
    [child.cpp, config.h, rotary_encoders.cpp]
2026-04-10 made a standalone test for the rotary encoders
2026-04-10 fix: updated rotary encoder and stepper based on copilot review of the PR
    [config.h, rotary_encoders.cpp, stepper_driver.cpp]
2026-04-10 fix: pre-increment current array pointer when iterating thorug mux
    [current_sensors.cpp]
2026-04-10 chnaged saving interrupt state to inline asm to make sure interrupts dont get reenabled inside interrupt context + mino stepper naming fix
    [rotary_encoders.cpp, stepper_driver.cpp]
2026-04-10 oops mustve clicked somehtign before adding - fixed now
    [rotary_encoders.cpp]
2026-04-10 addressed minor bugs throughout the codebase
    [child.cpp, rotary_encoders.cpp, stepper_driver.cpp]
2026-04-10 fix: adjusted pins on encoders and feat: added plotting of sesnor data
    [child.cpp, config.h, main.cpp]
2026-04-10 added current version of control board
    [UPGRADED_CONTROL_BOARD.kicad_pcb, UPGRADED_CONTROL_BOARD.kicad_sch, VibMotor.kicad_pcb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]
2026-04-12 fixed data hex command, teleplot
    [child.cpp, config.h]
2026-04-13 fixed test framework
2026-04-13 fix: fixed stepper duty cycle and direction
    [config.h, stepper_driver.cpp]
2026-04-13 fix: changed depo command interprtation to match software spec
    [child.cpp, config.h]
2026-04-13 moved documentation to root of projects
    [2025-2026 Software & EE Hex Value Key - 2024-2025 Manual Control Actions.csv]
2026-04-13 Fixed Copilot bugs in child.cpp and string_pot.cpp
    [child.cpp, string_pot.cpp]
2026-04-14 feat: add string potentiometer states and string pot pin
2026-04-14 fixed compilation bug in config
    [config.h]
2026-04-16 feat: implement depo door control with current sensing and state monitoring, also have a test script
2026-04-16 Load cell testing for teensy
2026-04-16 addressed issues from pr #25
    [child.cpp, config.h, string_pot.cpp]
2026-04-17 fix: request event now returns a cached distane so we dont read ADC from an ISR context and instead update periodically
    added GetSTate for exposing state
    moved defines to config
    [child.cpp, string_pot.cpp]
2026-04-17 resetting amps for depo door, increased current update speed udpated plot data to sued cached reads
    [child.cpp]
2026-04-17 reordered string pot state chcking to prevent 'moving' from masking a threshold breach
    [string_pot.cpp]
2026-04-17 fix: addressed belt-stepper mix-up
2026-04-17 Fix grp_DepositionDoor: 0=open, 1=close (was inverted via GET_DIRECTION); reject unknown params - Simplify DepoDoorState to 4 states: CLOSED, OPENED, OPENING, CLOSING — init defaults to CLOSED, timeo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
    [child.cpp]
2026-04-17 fix: removed references to stopexavation in system, handled by implementing estop in excavation subsystem driver and giving system access
    [child.cpp]
2026-04-17 moved child to main and creared subsstem driver for loco
2026-04-18 Update I2C pin definitions for Teensy 4.1
2026-04-18 Swap I2C SDA and SCL pin definitions
2026-04-18 added a sensor calibration env in parent
2026-04-18 added varible stepper speeds for going up and down
2026-04-18 fix: accounted for ramping deceleration in retunrign belt active status
    [config.h]
2026-04-18 adjusted current sensor settings
2026-04-18 fixed string pot constants
    [config.h]
2026-04-18 fix: imporcved the stepper timing to prevent stalls
    [config.h]
2026-04-18 changed depo door driver to use h-brdge
2026-04-18 fix: removed arming delay from depo door
    [config.h]
2026-04-19 fix: added some more logging for e-stops and timeouts, and added state tracking to prevent repeating prints
    [main.cpp]
2026-04-19 fix: ensured commands are only processed if relay indicates e-stop is released, and esured corrupted jetson commands arent executed
    [main.cpp]
2026-04-19 fix: last command time gets updated regardless of estop status
    [main.cpp]
2026-04-19 fix:lowered locomotion-while-excavatign duty cycle
    [config.h]
2026-04-20 fix: small typo in keyboard.cpp
    [keyboard.cpp]
2026-04-20 added a pyython pygame script to connect xbox controller to lapotp to teensy
2026-04-20 added explicit vib motor e-stop
2026-05-02 fix: update load cell loop and locomotion stall docs
    Agent-Logs-Url: https://github.com/nyu-rdt/RDT26-EE/sessions/5525a9b4-47a0-4808-afc6-05fb2452294a
    [main.cpp]
2026-05-02 fix: moved setting flags to dedicated function, made them volatile
    [comms.cpp, main.cpp]
2026-05-02 minor fix: changed variable types for safety
    [config.h, stepper_driver.cpp]
2026-05-02 fix: excav stall flag stays on until motor stopped chore: moved slew to its own file since its used in two drivers
2026-05-02 created shared state implem and i2c task
2026-05-02 fix: addressed non-volatility and race condition conecrns. marked some more things volatile and added comments where i determiend there wasnt actually an issue
    [rtos_config.h]
2026-05-02 replaced pin numbers with constants
    [app_init.cpp]
2026-05-02 feat(rtos): implement SafetyTask with relay read, egSafetyBits, and hard-stop notifications
2026-05-02 feat: implemented CmdDecodeTask with kill-switch gating and DesiredState writes
2026-05-02 fix: moved can from static in app to global in shared state
    [app_init.cpp]
2026-05-02 fix: reordered slew in CAN to happen only if rover not stopped to enforce immediate stop
    [task_motor_control.cpp]
2026-05-02 feat: implement SensorTask with current mux stepping and string pot read"
2026-05-02 fix: changed can timeout to max delay
    [task_motor_control.cpp]
2026-05-02 feat: changed sensor task to read one channel per update
2026-05-02 feat: added encoders
2026-05-02 added serial debug and CAN simulation to troubleshoot hang issue
    [app_init.cpp, rtos_config.h, task_debug.cpp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]
2026-05-02 fix: disabled can irq since it preempted the systick and starved the scheduler. added explanatory comments for future maintainters
    [app_init.cpp]
2026-05-02 fix: unterminated #if for sensor stirng pot enabled in task_mechanism
2026-05-02 (WIP) feat: added load cell driver + telemetry. needs to be udpated with scales obtained from testing
2026-05-02 fix: flip depo door directions in driver to match current mechanical design
2026-05-02 added sensors to dashbaord in rtos
2026-05-02 chnaged data request in i2c parent read match curent child impementaton
2026-05-02 fix: address sensor issues from PR review
    [keyboard.cpp, rtos_config.h]
2026-05-02 fix: get rid of lastcommandtime udpate in loop of superloop
    [main.cpp]
2026-10-07 renamed folder and added final files
    [FINAL_CONTROL_BOARD.kicad_pcb, FINAL_CONTROL_BOARD.kicad_sch, VibMotor.kicad_pcb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]
